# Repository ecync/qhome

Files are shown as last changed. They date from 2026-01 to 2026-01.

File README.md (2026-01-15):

# QHome Automation System

## 🏠 Project Overview
**QHome** is a comprehensive, full-stack IoT Smart Home solution designed to provide real-time monitoring, automation, and remote control of environmental and power sensors. The system is built on a modular architecture, spanning from custom PCB hardware design to a modern web-based dashboard.

This project integrates embedded systems connectivity (ESP32/ESP8266), robust backend services (NestJS/MQTT), and an interactive frontend (React) to create a seamless smart home experience.

## 🏗️ System Architecture

The system operates on a publish-subscribe model using MQTT for low-latency communication between the hardware nodes and the server.

```mermaid
graph LR
    subgraph Hardware Layer
        Node[ESP32 QHome Node]
        Sensors[Sensors: DHT, MQ, ACS, ZMPT]
        Relays[Relays & Actuators]
        Node --- Sensors
        Node --- Relays
    end

    subgraph Communication
        MQTT[MQTT Broker]
        WiFi[WiFi Network]
        Node -.->|MQTT/WS| WiFi
        WiFi -.-> MQTT
    end

    subgraph Cloud/Server Layer
        Backend[NestJS Backend]
        DB[(MongoDB)]
        Backend <-->|Pub/Sub| MQTT
        Backend <-->|Data Persistence| DB
    end

    subgraph User Interface
        Frontend[React Dashboard]
        User((User))
        User --> Frontend
        Frontend <-->|HTTP/REST| Backend
        Frontend <-->|Socket.io| Backend
    end
```

## 📊 Data Flow Diagram

This diagram illustrates how data moves through the entire system, from sensor acquisition to user visualization.

```mermaid
flowchart TB
    subgraph IoT_Node["IoT Node Layer"]
        Sensors[Physical Sensors<br/>DHT, MQ, ACS, ZMPT, PIR, LDR]
        ADC[Analog-to-Digital<br/>Conversion]
        Process[Data Processing<br/>& Aggregation]
        JSON[JSON Payload<br/>Generation]
        
        Sensors -->|Analog/Digital| ADC
        ADC -->|Raw Values| Process
        Process -->|Structured Data| JSON
    end
    
    subgraph Communication_Layer["Communication Layer"]
        WiFi[WiFi Module]
        MQTT_Pub[MQTT Publisher<br/>Topic: node/send]
        MQTT_Broker[MQTT Broker<br/>158.101.98.79:9001]
        MQTT_Sub[MQTT Subscriber<br/>Topic: node/cmd]
        
        JSON -->|Transmit| WiFi
        WiFi -->|Publish| MQTT_Pub
        MQTT_Pub -->|WebSocket| MQTT_Broker
        MQTT_Broker -->|Commands| MQTT_Sub
        MQTT_Sub -->|Receive| WiFi
    end
    
    subgraph Backend_Layer["Backend Service Layer"]
        Gateway[MQTT Gateway<br/>Service]
        Validator[Data Validator<br/>& Parser]
        EventEmitter[Event Emitter]
        DB_Write[Database Writer]
        Socket_Emit[Socket.IO Emitter]
        MongoDB[(MongoDB<br/>Collections)]
        API[REST API<br/>Controllers]
        
        MQTT_Broker -->|Subscribed Data| Gateway
        Gateway -->|Validate| Validator
        Validator -->|Emit Events| EventEmitter
        EventEmitter -->|Store| DB_Write
        EventEmitter -->|Broadcast| Socket_Emit
        DB_Write -->|Persist| MongoDB
        API -->|Query| MongoDB
    end
    
    subgraph Frontend_Layer["Frontend Application Layer"]
        Socket_Client[Socket.IO Client]
        State[React State<br/>Management]
        UI_Dashboard[Dashboard UI<br/>Components]
        UI_Analytics[Analytics UI<br/>Charts]
        HTTP_Client[HTTP Client<br/>API Service]
        
        Socket_Emit -.->|Real-time Push| Socket_Client
        Socket_Client -->|Update| State
        HTTP_Client -->|Fetch Historical| API
        API -->|Response| HTTP_Client
        HTTP_Client -->|Update| State
        State -->|Render| UI_Dashboard
        State -->|Render| UI_Analytics
    end
    
    subgraph User_Layer["User Interaction"]
        User((User))
        Browser[Web Browser]
        
        User -->|View/Control| Browser
        Browser <-->|Display| UI_Dashboard
        Browser <-->|Display| UI_Analytics
        Browser -->|Commands| HTTP_Client
    end
    
    HTTP_Client -.->|Control Commands| API
    API -.->|Publish to node/cmd| MQTT_Broker
    
    style IoT_Node fill:#e1f5ff
    style Communication_Layer fill:#fff3e0
    style Backend_Layer fill:#f3e5f5
    style Frontend_Layer fill:#e8f5e9
    style User_Layer fill:#fce4ec
```

### Data Flow Description

**1. Sensor Data Acquisition (IoT Node)**
- Physical sensors continuously monitor environmental and power parameters
- Analog sensors output voltage levels converted to digital values via ADC
- Data is processed, calibrated, and packaged into JSON format

**2. Data Transmission (Communication Layer)**
- JSON payload transmitted over WiFi to MQTT broker
- Published to `node/send` topic via WebSocket protocol
- Bidirectional communication allows receiving commands on `node/cmd` topic

**3. Data Processing (Backend Service)**
- MQTT Gateway subscribes to node data streams
- Incoming data is validated and parsed
- Event system triggers parallel operations:
  - Persistent storage in MongoDB collections
  - Real-time broadcast to connected frontend clients via Socket.IO

**4. Data Presentation (Frontend Application)**
- Socket.IO client receives real-time updates for live dashboard
- HTTP client fetches historical data for analytics and trends
- React state management updates UI components reactively

**5. User Control Loop**
- User interactions trigger API calls to backend
- Backend publishes control commands to MQTT broker
- IoT node receives and executes commands (relay control, configuration updates)

## 🔄 Software Flow Diagram

This diagram shows the complete software execution flow from system startup to continuous operation.

```mermaid
flowchart TD
    Start([System Power On]) --> Init_Check{Component<br/>Ready?}
    
    Init_Check -->|Hardware| Init_Hardware[Initialize Hardware<br/>• GPIO Pins<br/>• LCD Display<br/>• Sensors<br/>• Relays]
    Init_Check -->|Backend| Init_Backend[Initialize Backend<br/>• Load Config<br/>• Connect MongoDB<br/>• Start HTTP Server]
    Init_Check -->|Frontend| Init_Frontend[Initialize Frontend<br/>• Load React App<br/>• Check Session<br/>• Setup Routes]
    
    Init_Hardware --> Check_Config{Config<br/>Exists?}
    Check_Config -->|No| AP_Mode[Start WiFi AP Mode<br/>Show Config Portal]
    AP_Mode --> Wait_Config[Wait for User<br/>to Configure WiFi]
    Wait_Config -->|Configured| Save_Config[Save to EEPROM]
    Save_Config --> Connect_WiFi
    
    Check_Config -->|Yes| Connect_WiFi[Connect to WiFi]
    Connect_WiFi --> WiFi_Success{Connected?}
    WiFi_Success -->|No| AP_Mode
    WiFi_Success -->|Yes| Connect_MQTT[Connect to<br/>MQTT Broker]
    
    Connect_MQTT --> MQTT_Success{Connected?}
    MQTT_Success -->|No| Retry_MQTT[Retry Connection<br/>Exponential Backoff]
    Retry_MQTT --> MQTT_Success
    MQTT_Success -->|Yes| Subscribe_Topics[Subscribe to<br/>node/cmd Topic]
    
    Init_Backend --> Connect_DB[Connect to MongoDB]
    Connect_DB --> DB_Success{Connected?}
    DB_Success -->|No| Error_Exit[Log Error & Exit]
    DB_Success -->|Yes| Connect_MQTT_Backend[Connect to<br/>MQTT Broker as Client]
    Connect_MQTT_Backend --> Backend_Subscribe[Subscribe to<br/>node/send Topic]
    Backend_Subscribe --> Start_API[Start REST API<br/>& Socket.IO Server]
    
    Init_Frontend --> Check_Auth{User<br/>Authenticated?}
    Check_Auth -->|No| Show_Login[Show Login Page]
    Show_Login --> User_Login[User Enters<br/>Credentials]
    User_Login --> Validate_Auth[Validate Against<br/>Backend API]
    Validate_Auth --> Auth_Valid{Valid?}
    Auth_Valid -->|No| Show_Login
    Auth_Valid -->|Yes| Store_Session[Store Session<br/>in SessionStorage]
    
    Check_Auth -->|Yes| Load_Dashboard
    Store_Session --> Load_Dashboard[Load Dashboard<br/>Components]
    Load_Dashboard --> Connect_Socket[Connect Socket.IO<br/>to Backend]
    
    Subscribe_Topics --> Ready_Node[Node Ready<br/>Play Beep Sound]
    Start_API --> Ready_Backend[Backend Ready<br/>Log Status]
    Connect_Socket --> Ready_Frontend[Frontend Ready<br/>Display Dashboard]
    
    Ready_Node --> Main_Loop_Node[Main Loop: Node]
    Ready_Backend --> Main_Loop_Backend[Main Loop: Backend]
    Ready_Frontend --> Main_Loop_Frontend[Main Loop: Frontend]
    
    Main_Loop_Node --> Read_Sensors[Read All Sensors<br/>Every Interval]
    Read_Sensors --> Process_Data[Process & Calculate<br/>• Temperature/Humidity<br/>• Gas Level<br/>• Power/Energy<br/>• Motion/Light]
    Process_Data --> Check_Thresholds{Thresholds<br/>Exceeded?}
    Check_Thresholds -->|Yes| Trigger_Alert[Trigger Local Alert<br/>• Activate Buzzer<br/>• Update LCD<br/>• Send MQTT Alert]
    Check_Thresholds -->|No| Check_Sync
    Trigger_Alert --> Check_Sync
    
    Check_Sync{Time to<br/>Sync?} -->|Yes| Publish_Data[Publish JSON<br/>to node/send]
    Check_Sync -->|No| Update_Display
    Publish_Data --> Update_Display[Update LCD<br/>Display Status]
    
    Update_Display --> Listen_Commands[Listen for<br/>MQTT Commands]
    Listen_Commands --> Command_Received{Command?}
    Command_Received -->|Yes| Execute_Command[Execute Command<br/>• Toggle Relay<br/>• Update Config<br/>• Restart]
    Command_Received -->|No| Main_Loop_Node
    Execute_Command --> Main_Loop_Node
    
    Main_Loop_Backend --> Listen_MQTT[Listen for<br/>MQTT Messages]
    Listen_MQTT --> MQTT_Message{Message<br/>Received?}
    MQTT_Message -->|Yes| Parse_Message[Parse Message Type<br/>• _sensor_data<br/>• _alert<br/>• _error<br/>• _ack]
    MQTT_Message -->|No| Handle_HTTP
    
    Parse_Message --> Save_DB[Save to MongoDB<br/>Appropriate Collection]
    Save_DB --> Emit_Socket[Emit to Socket.IO<br/>Connected Clients]
    Emit_Socket --> Handle_HTTP
    
    Handle_HTTP[Handle HTTP Requests<br/>• GET sensor-data<br/>• POST commands<br/>• POST config]
    Handle_HTTP --> API_Request{Request?}
    API_Request -->|GET| Query_DB[Query MongoDB<br/>Return Results]
    API_Request -->|POST| Publish_Command[Publish to<br/>node/cmd Topic]
    API_Request -->|None| Main_Loop_Backend
    Query_DB --> Main_Loop_Backend
    Publish_Command --> Main_Loop_Backend
    
    Main_Loop_Frontend --> Socket_Listen[Listen for<br/>Socket.IO Events]
    Socket_Listen --> Socket_Event{Event<br/>Received?}
    Socket_Event -->|Yes| Update_State[Update React State<br/>Trigger Re-render]
    Socket_Event -->|No| User_Action
    Update_State --> User_Action
    
    User_Action{User<br/>Action?}
    User_Action -->|View Analytics| Fetch_History[Fetch Historical<br/>Data via API]
    User_Action -->|Send Command| Send_Command[Send POST Request<br/>to Backend API]
    User_Action -->|Update Settings| Send_Config[Send Config Update<br/>to Backend API]
    User_Action -->|None| Main_Loop_Frontend
    
    Fetch_History --> Render_Charts[Render Charts<br/>with Recharts]
    Render_Charts --> Main_Loop_Frontend
    Send_Command --> Main_Loop_Frontend
    Send_Config --> Main_Loop_Frontend
    
    style Init_Hardware fill:#e1f5ff
    style Init_Backend fill:#f3e5f5
    style Init_Frontend fill:#e8f5e9
    style Main_Loop_Node fill:#ffebee
    style Main_Loop_Backend fill:#fff3e0
    style Main_Loop_Frontend fill:#e0f2f1
```

## 📂 Project Modules

The repository is organized into four main operational layers. Click on the module links for detailed documentation, installation steps, and API references.

| Module | Directory | Description | Technology |
| :--- | :--- | :--- | :--- |
| **Hardware Design** | [**`/pcb`**](pcb/README.md) | Custom PCB layouts, schematics, and BOM. | Eagle CAD / Fusion 360 |
| **Firmware** | [**`/node`**](node/README.md) | C++ firmware for ESP controllers implementing sensor logic. | Arduino / C++ |
| **Backend API** | [**`/backend`**](backend/README.md) | Server logic, database management, and MQTT processing. | NestJS, MongoDB, TypeScript |
| **Frontend UI** | [**`/frontend`**](frontend/README.md) | Web dashboard for monitoring and control. | React, Vite, Tailwind CSS |

## ✨ Key Features

*   **Real-time Monitoring**: Live streaming of Temperature, Humidity, Air Quality (Gas), and Ambient Light levels.
*   **Energy Management**: Precise AC Voltage, Current, Power (W), and Energy (kWh) metering using ZMPT101B and ACS712 sensors.
*   **Safety & Alerts**: Instant automated alerts for gas leaks, fire detection, or abnormal power usage via Buzzer and MQTT push notifications.
*   **Remote Control**: Toggle lights and appliances remotely via the web dashboard.
*   **Data Analytics**: Historical charts and graphs to track power consumption and environmental trends over time.
*   **Secure Access**: Token-based authentication (Custom Headers) ensuring only authorized users can control the system.

## 🚀 Getting Started

To spin up the entire system locally, follow the **Installation & Setup** guides in each module's README. A high-level startup order is recommended:

1.  **Infrastructure**: Ensure you have a MongoDB instance and an MQTT Broker (e.g., Mosquitto) running.
2.  **Backend**: Start the [Backend Service](backend/README.md) to initialize the API and Database connections.
3.  **Frontend**: Launch the [Web Dashboard](frontend/README.md) to interact with the system.
4.  **Hardware**: Flash the [Firmware](node/README.md) to your ESP32/ESP8266 device and configure it to connect to your Wi-Fi and MQTT Broker.

## 🛠️ Technology Stack

*   **Hardware**: ESP32, ESP8266, DHT11/22, MQ-135, ACS712, ZMPT101B, Relay Modules.
*   **Protocol**: MQTT (Message Queuing Telemetry Transport) over WebSockets.
*   **Server**: Node.js, NestJS, Mongoose.
*   **Database**: MongoDB (NoSQL).
*   **Client**: React.js, TypeScript, Tailwind CSS, Recharts.

---
*Developed by Eshan Chathuranga*

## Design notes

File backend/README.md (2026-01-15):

# Backend Service - QHome Automation System

## Overview
The **Backend Service** acts as the central intelligence of the Home Automation System. It is built with **NestJS** and serves two primary roles:
1.  **API Server**: Provides a RESTful API for the frontend dashboard to fetch data and update settings.
2.  **MQTT Broker/Client**: Connects to the IoT Nodes via MQTT (over WebSockets) to receive sensor telemetry and dispatch control commands.

## Technology Stack

| Category | Technology | Usage |
| :--- | :--- | :--- |
| **Framework** | [NestJS](https://nestjs.com/) | Server-side application framework |
| **Language** | [TypeScript](https://www.typescriptlang.org/) | Type-safe development |
| **Database** | [MongoDB](https://www.mongodb.com/) | NoSQL database for flexible sensor data storage |
| **ODM** | [Mongoose](https://mongoosejs.com/) | Object Data Modeling for MongoDB |
| **Messaging** | [MQTT](https://mqtt.org/) | IoT communication protocol |
| **Runtime** | [Node.js](https://nodejs.org/) | JavaScript runtime environment |

## Architecture

The backend follows a modular monolith architecture provided by NestJS.

```mermaid
graph TD
    Device[IoT Node] -->|MQTT Publish| Broker[MQTT Broker]
    Broker -->|Subscribe| NestJS[NestJS Backend]
    
    NestJS -->|Process| MqttService[MQTT Service]
    
    MqttService -->|Save Data| MongoDB[(MongoDB Database)]
    MqttService -->|Events| EventEmitter[Event Emitter]
    
    User[Frontend User] -->|HTTP Req| API[REST API Controller]
    API -->|Auth Guard| Auth[Authentication]
    Auth -- Valid --> Service[App Service]
    Service -->|Query| MongoDB
    
    Service -->|Command| MqttService
    MqttService -->|Publish| Broker
    Broker -->|Receive| Device
```

## 🔄 Data Processing Flow

This diagram details how the backend processes incoming MQTT messages and serves data to clients.

```mermaid
flowchart TD
    Start([MQTT Message Received]) --> Gateway[MQTT Gateway<br/>mqtt.gateway.ts]
    Gateway --> ParseMessage{Parse Message<br/>Structure}
    
    ParseMessage -->|Valid JSON| ExtractType[Extract Message Type<br/>from payload.type]
    ParseMessage -->|Invalid| LogError[Log Parse Error]
    LogError --> SendErrorResponse[Emit Error Event]
    SendErrorResponse --> End1([End])
    
    ExtractType --> TypeSwitch{Message Type?}
    
    TypeSwitch -->|_sensor_data| ProcessSensor[Process Sensor Data]
    TypeSwitch -->|_alert| ProcessAlert[Process Alert]
    TypeSwitch -->|_error| ProcessError[Process Error]
    TypeSwitch -->|_ack| ProcessAck[Process Acknowledgment]
    TypeSwitch -->|Unknown| LogUnknown[Log Unknown Type]
    LogUnknown --> End2([End])
    
    ProcessSensor --> ValidateSensor[Validate Sensor Schema<br/>• Check required fields<br/>• Validate data types<br/>• Range validation]
    ValidateSensor --> SensorValid{Valid?}
    SensorValid -->|No| LogValidationError[Log Validation Error]
    LogValidationError --> End3([End])
    
    SensorValid -->|Yes| TransformData[Transform Data<br/>• Convert units<br/>• Calculate derived values<br/>• Add timestamp]
    TransformData --> CreateSensorDoc[Create NodeSensorData<br/>Document]
    
    CreateSensorDoc --> SaveSensor[Save to MongoDB<br/>nodeSensorData collection]
    SaveSensor --> SensorSaved{Saved?}
    SensorSaved -->|Error| LogDBError1[Log Database Error]
    LogDBError1 --> End4([End])
    
    SensorSaved -->|Success| EmitSensorEvent[Emit 'sensorUpdate' Event]
    EmitSensorEvent --> BroadcastSocket1[Broadcast via Socket.IO<br/>to all connected clients]
    BroadcastSocket1 --> CheckThresholds[Check Alert Thresholds<br/>• Temperature limits<br/>• Gas levels<br/>• Power anomalies]
    CheckThresholds --> ThresholdExceeded{Threshold<br/>Exceeded?}
    ThresholdExceeded -->|Yes| CreateAutoAlert[Create Automatic Alert]
    CreateAutoAlert --> ProcessAlert
    ThresholdExceeded -->|No| End5([End])
    
    ProcessAlert --> ValidateAlert[Validate Alert Schema<br/>• alert_type required<br/>• Validate severity]
    ValidateAlert --> AlertValid{Valid?}
    AlertValid -->|No| LogAlertError[Log Validation Error]
    LogAlertError --> End6([End])
    
    AlertValid -->|Yes| EnrichAlert[Enrich Alert Data<br/>• Add timestamp<br/>• Add severity level<br/>• Add node identifier]
    EnrichAlert --> CreateAlertDoc[Create NodeAlert<br/>Document]
    CreateAlertDoc --> SaveAlert[Save to MongoDB<br/>nodeAlert collection]
    SaveAlert --> AlertSaved{Saved?}
    AlertSaved -->|Error| LogDBError2[Log Database Error]
    LogDBError2 --> End7([End])
    
    AlertSaved -->|Success| EmitAlertEvent[Emit 'criticalAlert' Event]
    EmitAlertEvent --> BroadcastSocket2[Broadcast via Socket.IO<br/>HIGH PRIORITY]
    BroadcastSocket2 --> TriggerNotification[Trigger Push Notification<br/>If configured]
    TriggerNotification --> End8([End])
    
    ProcessError --> ValidateError[Validate Error Schema<br/>• error_type required<br/>• Validate message]
    ValidateError --> ErrorValid{Valid?}
    ErrorValid -->|No| LogErrorValidation[Log Validation Error]
    LogErrorValidation --> End9([End])
    
    ErrorValid -->|Yes| CreateErrorDoc[Create NodeError<br/>Document]
    CreateErrorDoc --> SaveError[Save to MongoDB<br/>nodeError collection]
    SaveError --> ErrorSaved{Saved?}
    ErrorSaved -->|Error| LogDBError3[Log Database Error]
    LogDBError3 --> End10([End])
    
    ErrorSaved -->|Success| EmitErrorEvent[Emit 'systemError' Event]
    EmitErrorEvent --> BroadcastSocket3[Broadcast via Socket.IO]
    BroadcastSocket3 --> CheckCritical{Critical<br/>Error?}
    CheckCritical -->|Yes| SendAdminAlert[Send Admin Notification]
    SendAdminAlert --> End11([End])
    CheckCritical -->|No| End12([End])
    
    ProcessAck --> LogAck[Log Acknowledgment]
    LogAck --> UpdateCommandStatus[Update Command Status<br/>In tracking system]
    UpdateCommandStatus --> EmitAckEvent[Emit 'commandAck' Event]
    EmitAckEvent --> BroadcastSocket4[Broadcast via Socket.IO]
    BroadcastSocket4 --> End13([End])
    
    style ProcessSensor fill:#e3f2fd
    style ProcessAlert fill:#ffebee
    style ProcessError fill:#fff3e0
    style ProcessAck fill:#e8f5e9
    style SaveSensor fill:#f3e5f5
    style SaveAlert fill:#f3e5f5
    style SaveError fill:#f3e5f5
```

### Data Processing Pipeline Stages

**1. Message Reception & Parsing**
- MQTT Gateway receives raw message from broker
- JSON parsing with error handling
- Message type extraction from payload structure

**2. Validation Layer**
- Schema validation using TypeScript interfaces
- Required field verification
- Data type and range checks
- Malformed data rejection with logging

**3. Data Transformation**
- Unit conversions (e.g., ADC values to physical units)
- Calculated fields (e.g., power = voltage × current)
- Timestamp normalization
- Data enrichment with metadata

**4. Persistence Layer**
- Mongoose ODM for MongoDB operations
- Atomic write operations
- Error handling and retry logic
- Index optimization for queries

**5. Event Broadcasting**
- Event-driven architecture using NestJS EventEmitter
- Socket.IO real-time push to connected clients
- Priority-based message queuing for alerts
- Client-specific filtering and routing

**6. Threshold Monitoring**
- Continuous evaluation of sensor values against configured thresholds
- Automatic alert generation for anomalies
- Cascading alert processing
- Rate limiting to prevent alert storms

---

## 🌐 REST API Request Flow

```mermaid
flowchart TD
    HTTPRequest([HTTP Request]) --> Controller[API Controller<br/>@Controller /mqtt]
    Controller --> CheckAuth{Authentication<br/>Guard}
    
    CheckAuth -->|Missing Headers| Return401[Return 401<br/>Unauthorized]
    Return401 --> EndReq1([End Request])
    
    CheckAuth -->|Invalid Credentials| Return403[Return 403<br/>Forbidden]
    Return403 --> EndReq2([End Request])
    
    CheckAuth -->|Valid| RouteMethod{Route<br/>Method?}
    
    RouteMethod -->|GET /status| GetStatus[Query NodeConfig<br/>from MongoDB]
    GetStatus --> ReturnConfig[Return 200<br/>with config JSON]
    ReturnConfig --> EndReq3([End Request])
    
    RouteMethod -->|GET /errors| GetErrors[Query NodeError<br/>Collection]
    GetErrors --> ApplyLimit[Apply Limit Query Param]
    ApplyLimit --> SortDesc[Sort by createdAt DESC]
    SortDesc --> ReturnErrors[Return 200<br/>with error array]
    ReturnErrors --> EndReq4([End Request])
    
    RouteMethod -->|GET /alerts| GetAlerts[Query NodeAlert<br/>Collection]
    GetAlerts --> ApplyLimitAlerts[Apply Limit Query Param]
    ApplyLimitAlerts --> SortDescAlerts[Sort by createdAt DESC]
    SortDescAlerts --> ReturnAlerts[Return 200<br/>with alert array]
    ReturnAlerts --> EndReq5([End Request])
    
    RouteMethod -->|GET /sensor-data/:date| ParseDate[Parse Date Parameter]
    ParseDate --> DateValid{Valid<br/>Timestamp?}
    DateValid -->|No| Return400[Return 400<br/>Bad Request]
    Return400 --> EndReq6([End Request])
    DateValid -->|Yes| QueryByDate[Query NodeSensorData<br/>by date range]
    QueryByDate --> Aggregate[Aggregate & Group Data]
    Aggregate --> ReturnData[Return 200<br/>with sensor data array]
    ReturnData --> EndReq7([End Request])
    
    RouteMethod -->|POST /command/:cmd| ValidateCommand[Validate Command Type]
    ValidateCommand --> CommandValid{Valid<br/>Command?}
    CommandValid -->|No| Return400Cmd[Return 400<br/>Invalid Command]
    Return400Cmd --> EndReq8([End Request])
    
    CommandValid -->|Yes| CreateCmdPayload["Create Command Payload<br/>{type: '_command', payload: {cmd: ...}}"]
    CreateCmdPayload --> PublishMQTT1[Publish to MQTT<br/>Topic: node/cmd]
    PublishMQTT1 --> MQTTPublished1{Published?}
    MQTTPublished1 -->|Error| Return500Pub1[Return 500<br/>Publish Failed]
    Return500Pub1 --> EndReq9([End Request])
    MQTTPublished1 -->|Success| Return202Cmd[Return 202<br/>Accepted]
    Return202Cmd --> EndReq10([End Request])
    
    RouteMethod -->|POST /config| ValidateConfigSchema[Validate Config Schema<br/>against interface]
    ValidateConfigSchema --> ConfigValid{Valid<br/>Schema?}
    ConfigValid -->|No| Return400Config[Return 400<br/>Invalid Config]
    Return400Config --> EndReq11([End Request])
    
    ConfigValid -->|Yes| UpdateDBConfig[Update NodeConfig<br/>in MongoDB]
    UpdateDBConfig --> DBUpdated{Updated?}
    DBUpdated -->|Error| Return500DB[Return 500<br/>Database Error]
    Return500DB --> EndReq12([End Request])
    
    DBUpdated -->|Success| CreateConfigPayload["Create Config Payload<br/>{type: '_config_update', payload: {config: ...}}"]
    CreateConfigPayload --> PublishMQTT2[Publish to MQTT<br/>Topic: node/cmd]
    PublishMQTT2 --> MQTTPublished2{Published?}
    MQTTPublished2 -->|Error| Return500Pub2[Return 500<br/>Publish Failed]
    Return500Pub2 --> EndReq13([End Request])
    MQTTPublished2 -->|Success| Return202Config[Return 202<br/>Accepted]
    Return202Config --> EndReq14([End Request])
    
    style CheckAuth fill:#ffebee
    style GetStatus fill:#e3f2fd
    style GetErrors fill:#e3f2fd
    style GetAlerts fill:#e3f2fd
    style QueryByDate fill:#e3f2fd
    style PublishMQTT1 fill:#fff3e0
    style PublishMQTT2 fill:#fff3e0
    style UpdateDBConfig fill:#f3e5f5
```

---

## Directory Structure
```
backend/
├── src/
│   ├── mqtt/               # MQTT Module
│   │   ├── mqtt.gateway.ts # Handles socket events
│   │   ├── mqtt.service.ts # Business logic for messaging
│   │   └── auth.guard.ts   # API Authentication
│   ├── schema/             # Mongoose Data Models
│   │   ├── node.sensor.data.schema.ts
│   │   ├── node.config.schema.ts
│   │   └── ...
│   ├── app.module.ts       # Root Module
│   └── main.ts             # Entry point
└── package.json
```

## Documentation
- [API Reference](API.md) - Detailed description of HTTP Endpoints and MQTT topics.

## Data Models

The system uses MongoDB schemas to organize data:

*   **NodeSensorData**: Stores historical readings (Temp, Humidity, Gas, Light, Power).
*   **NodeConfig**: Remote configuration for nodes (Thresholds, Intervals).
*   **NodeAlert**: Critical events (Gas leak, Fire detection).
*   **NodeError**: System health logs (Sensor failures).

## API & Authentication

### Security
The API is protected using custom headers. All HTTP requests must include:
*   `X-USERNAME`: Configured username
*   `X-PASSWORD`: Configured password

### Integration
The backend connects to an MQTT broker over **WebSockets** (host: `158.101.98.79`, port: `9001`). This allows it to function in environments where raw TCP MQTT ports might be restricted, and enables easy integration with web-based clients.

## Installation & Setup

### Prerequisites
*   Node.js (v18+)
*   MongoDB Instance (Local or Atlas)
*   MQTT Broker (Mosquitto or similar, supporting WebSockets)

### Environment Variables
Create a `.env` file in the root directory:
```env
MONGO_URI=mongodb://localhost:27017/qhome
API_USERNAME=admin
API_PASSWORD=secret
PORT=3000
```

### Steps

1.  **Install Application**
    ```bash
    cd backend
    npm install
    ```

2.  **Start Development Server**
    ```bash
    npm run start:dev
    ```
    The server will start on `http://localhost:3000` (API) and connect to the MQTT Broker.

3.  **Build for Production**
    ```bash
    npm run build
    npm run start:prod
    ```

## Visuals
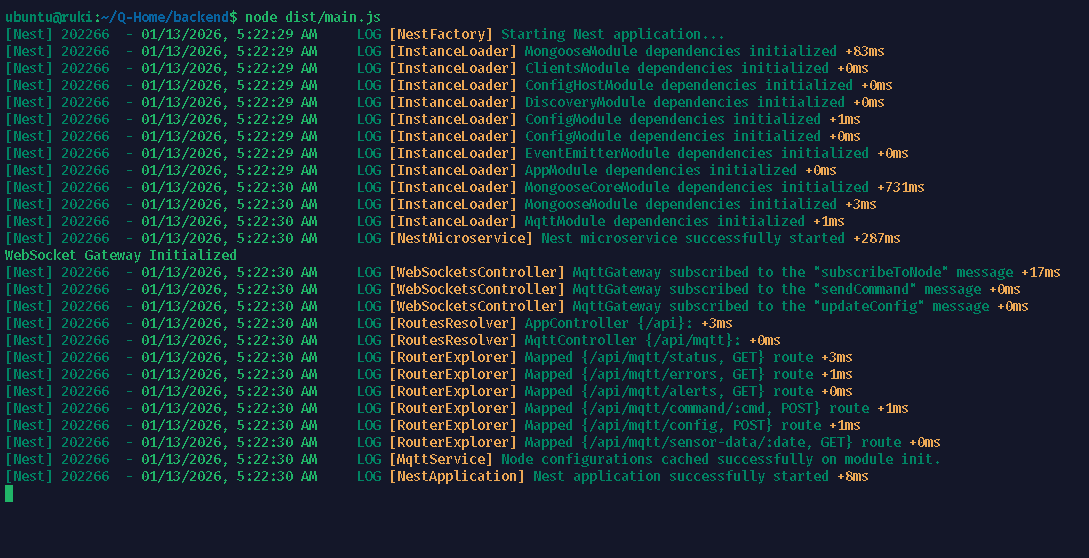
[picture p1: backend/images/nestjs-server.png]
NestJS Server Concept


---

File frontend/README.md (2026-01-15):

# Frontend Web Application - QHome Automation System

## Overview
The **Frontend Web Application** serves as the user interface for the Smart Home Automation System. Built with **React** and **Vite**, it provides a responsive, modern dashboard for real-time monitoring, control, and data analysis of connected IoT nodes.

## Features
- **📊 Real-time Dashboard**: Live monitoring of sensor data (Temperature, Humidity, Gas, Power, etc.) via Websockets/MQTT integration.
- **🔐 Secure Authentication**: User verification system protecting access to controls and configuration.
- **📈 Analytics**: Interactive charts visualizing historical sensor data using `recharts`.
- **⚙️ Remote Configuration**: Interface to update system settings and node parameters remotely.
- **📱 Responsive Design**: Built with **Tailwind CSS** for a seamless experience across desktop and mobile devices.

## Technology Stack

| Category | Technology | Usage |
| :--- | :--- | :--- |
| **Framework** | [React 18+](https://react.dev/) | Component-based UI architecture |
| **Build Tool** | [Vite](https://vitejs.dev/) | Ultra-fast development server and bundling |
| **Styling** | [Tailwind CSS](https://tailwindcss.com/) | Utility-first CSS framework |
| **Routing** | [React Router 6](https://reactrouter.com/) | Client-side navigation |
| **Charts** | [Recharts](https://recharts.org/) | Data visualization |
| **Icons** | [Lucide React](https://lucide.dev/) | Consistent & clean icon set |
| **Connectivity** | [Socket.io-client](https://socket.io/) | Real-time bidirectional communication |

## Application Structure

### Directory Layout
```
frontend/
├── src/
│   ├── components/     # UI Pages & Widgets
│   │   ├── Analytics.tsx
│   │   ├── Dashboard.tsx
│   │   ├── Layout.tsx
│   │   ├── Login.tsx
│   │   └── Settings.tsx
│   ├── hooks/          # Custom React Hooks
│   ├── utils/          # API & Helper functions
│   ├── App.tsx         # Main Routing Logic
│   └── main.tsx        # Entry Point
├── images/             # Documentation screenshots
└── package.json        # Dependencies & Scripts
```

## User Interface

### 1. Dashboard
The central hub displaying live cards for all active nodes.
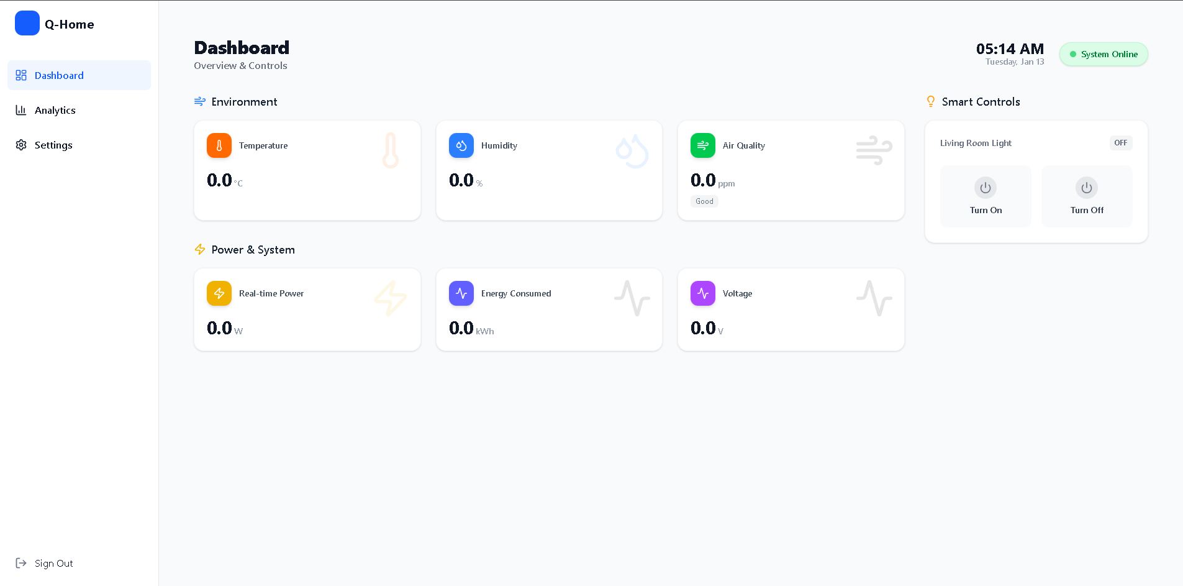
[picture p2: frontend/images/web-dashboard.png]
Dashboard


### 2. Analytics
Historical data visualization for power consumption and environmental trends.
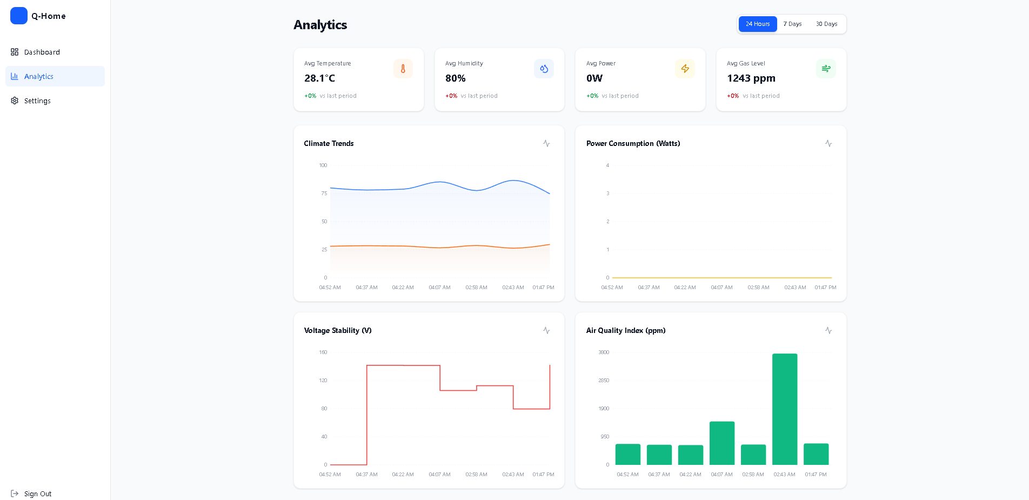
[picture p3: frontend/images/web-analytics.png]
Analytics


### 3. Settings
Configuration panel for user management and system preferences.
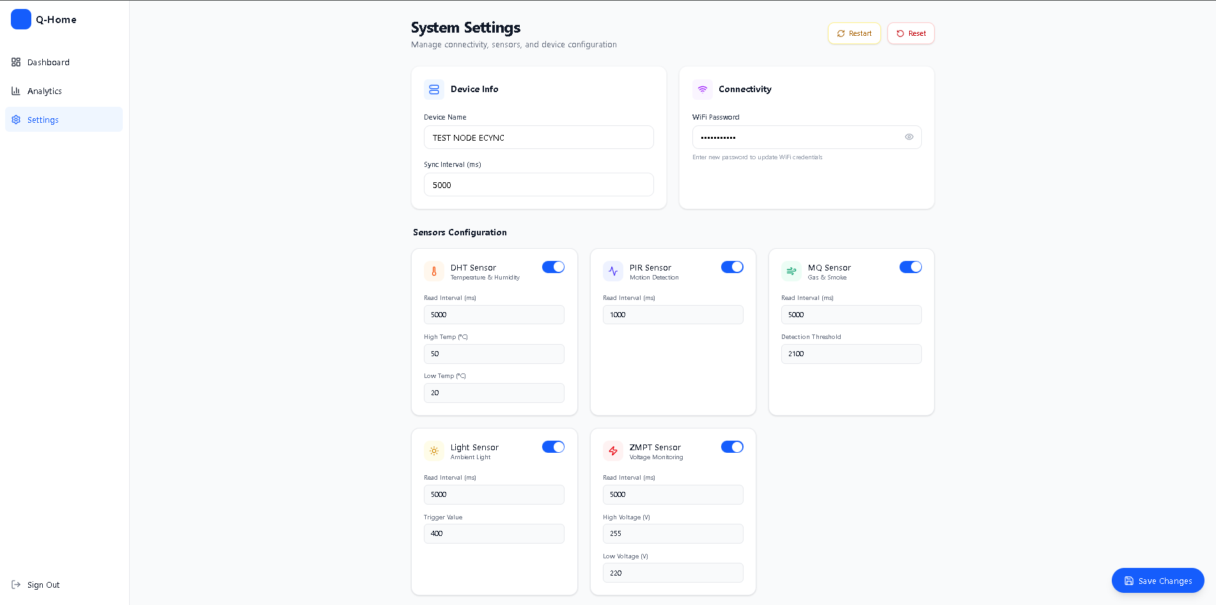
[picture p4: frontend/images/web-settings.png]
Settings


### 4. Login
Secure entry point.
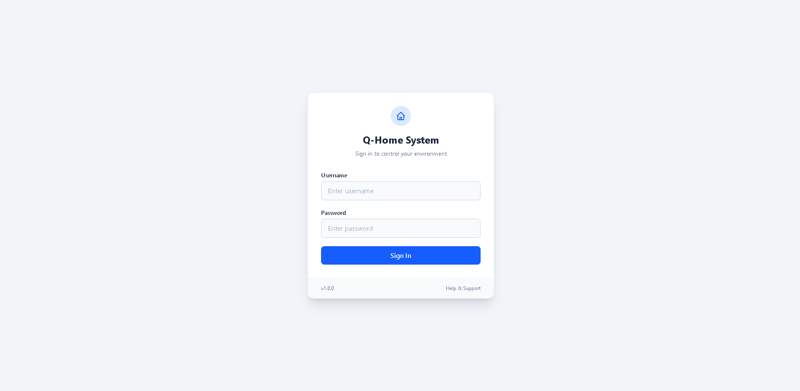
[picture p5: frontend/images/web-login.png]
Login


## System Architecture

### Application Flow
```mermaid
graph TD
    User((User)) -->|Visits| Browse[Browser]
    Browse -->|Checks Session| Auth{Authenticated?}
    
    Auth -- No --> Login[Login Page]
    Login -->|Credentials| API[Backend API]
    API -- Success --> Session[Set Session Storage]
    Session --> Dashboard
    
    Auth -- Yes --> Layout[Main Layout]
    
    Layout -->|route: /| Dashboard[Dashboard View]
    Layout -->|route: /analytics| Analytics[Analytics View]
    Layout -->|route: /settings| Settings[Settings View]
    
    Dashboard -->|Subscribes| Socket[Socket.IO / MQTT]
    Socket -->|Updates| LiveData[Real-time UI Updates]
```

## 👤 User Interaction Flow Diagram

This diagram shows detailed user journeys through the application and how actions trigger backend operations.

```mermaid
flowchart TD
    Start([User Opens Browser]) --> LoadApp[Load React Application]
    LoadApp --> CheckSession{Session<br/>Storage?}
    
    CheckSession -->|No Session| ShowLogin[Render Login Component]
    ShowLogin --> UserInput[User Enters<br/>Username & Password]
    UserInput --> ValidateInput{Input<br/>Validation}
    ValidateInput -->|Empty Fields| ShowInputError[Show Validation Error]
    ShowInputError --> UserInput
    
    ValidateInput -->|Valid| SendAuthRequest[POST Request to Backend<br/>Headers: X-USERNAME, X-PASSWORD]
    SendAuthRequest --> WaitResponse[Wait for Response]
    WaitResponse --> AuthResponse{Response?}
    
    AuthResponse -->|401/403| ShowAuthError[Show Authentication Error<br/>'Invalid Credentials']
    ShowAuthError --> UserInput
    
    AuthResponse -->|200 OK| SaveSession[Store Credentials<br/>in SessionStorage]
    SaveSession --> InitSocket[Initialize Socket.IO Connection]
    
    CheckSession -->|Valid Session| InitSocket
    InitSocket --> ConnectSocket[Connect to Backend<br/>ws://backend:3000]
    ConnectSocket --> SocketConnected{Connected?}
    SocketConnected -->|Error| ShowConnError[Show Connection Error<br/>Retry Logic]
    ShowConnError --> ConnectSocket
    
    SocketConnected -->|Success| SubscribeEvents[Subscribe to Socket Events<br/>• sensorUpdate<br/>• criticalAlert<br/>• commandAck<br/>• systemError]
    SubscribeEvents --> LoadLayout[Render Main Layout<br/>• Sidebar Navigation<br/>• Header with User Info<br/>• Content Outlet]
    
    LoadLayout --> NavigateDashboard[Default Route: Dashboard]
    
    NavigateDashboard --> RenderDashboard[Render Dashboard Component]
    RenderDashboard --> FetchInitialData[Fetch Initial Data<br/>GET /mqtt/status]
    FetchInitialData --> DisplayCards[Display Sensor Cards<br/>• Temperature/Humidity<br/>• Gas Level<br/>• Power Metrics<br/>• Light Status<br/>• Motion Status]
    
    DisplayCards --> MainLoop[Main Application Loop]
    
    MainLoop --> WaitEvent{User Action<br/>or Event?}
    
    WaitEvent -->|Socket: sensorUpdate| UpdateDashboard[Update Dashboard State<br/>Trigger Re-render]
    UpdateDashboard --> AnimateChange[Animate Value Changes]
    AnimateChange --> MainLoop
    
    WaitEvent -->|Socket: criticalAlert| ShowAlertModal[Show Alert Modal<br/>with Alert Details]
    ShowAlertModal --> PlayAlertSound[Play Alert Sound<br/>if enabled]
    PlayAlertSound --> MainLoop
    
    WaitEvent -->|Click: Quick Action Button| QuickAction{Action Type?}
    QuickAction -->|Toggle Light| SendToggleCmd[POST /mqtt/command/toggle_light]
    SendToggleCmd --> ShowLoading1[Show Loading Spinner]
    ShowLoading1 --> CmdResponse1{Response?}
    CmdResponse1 -->|202 Accepted| ShowSuccess1[Show Success Toast]
    ShowSuccess1 --> WaitAck1[Wait for Socket 'commandAck']
    WaitAck1 --> UpdateUI1[Update UI State]
    UpdateUI1 --> MainLoop
    CmdResponse1 -->|Error| ShowError1[Show Error Toast]
    ShowError1 --> MainLoop
    
    QuickAction -->|Restart System| ConfirmRestart[Show Confirmation Dialog]
    ConfirmRestart --> UserConfirm1{Confirmed?}
    UserConfirm1 -->|No| MainLoop
    UserConfirm1 -->|Yes| SendRestartCmd[POST /mqtt/command/restart]
    SendRestartCmd --> ShowLoading2[Show Loading Spinner]
    ShowLoading2 --> MainLoop
    
    WaitEvent -->|Click: Analytics Nav| NavigateAnalytics[Navigate to /analytics]
    NavigateAnalytics --> RenderAnalytics[Render Analytics Component]
    RenderAnalytics --> SelectDateRange[User Selects Date Range<br/>via Date Picker]
    SelectDateRange --> FetchHistorical[GET /mqtt/sensor-data/:date<br/>for each day in range]
    FetchHistorical --> ProcessData[Process & Aggregate Data<br/>• Calculate averages<br/>• Find min/max<br/>• Group by time intervals]
    ProcessData --> RenderCharts[Render Recharts Components<br/>• Line Chart: Temperature<br/>• Area Chart: Power Consumption<br/>• Bar Chart: Gas Levels]
    RenderCharts --> ChartsDisplayed[Display Interactive Charts<br/>with tooltips & zoom]
    ChartsDisplayed --> MainLoop
    
    WaitEvent -->|Click: Settings Nav| NavigateSettings[Navigate to /settings]
    NavigateSettings --> RenderSettings[Render Settings Component]
    RenderSettings --> DisplayForms[Display Configuration Forms<br/>• Node Settings<br/>• Sensor Thresholds<br/>• Sync Intervals]
    DisplayForms --> UserEditSettings[User Modifies Settings]
    UserEditSettings --> ValidateSettings{Valid<br/>Input?}
    ValidateSettings -->|No| ShowFormError[Show Form Validation Error]
    ShowFormError --> UserEditSettings
    
    ValidateSettings -->|Yes| ClickSave[User Clicks Save Button]
    ClickSave --> SendConfigUpdate[POST /mqtt/config<br/>Body: Updated Config JSON]
    SendConfigUpdate --> ShowLoading3[Show Loading Spinner]
    ShowLoading3 --> ConfigResponse{Response?}
    ConfigResponse -->|202 Accepted| ShowSuccess2[Show Success Toast<br/>'Configuration Updated']
    ShowSuccess2 --> WaitConfigAck[Wait for Socket 'configUpdated']
    WaitConfigAck --> RefreshSettings[Refresh Settings Display]
    RefreshSettings --> MainLoop
    ConfigResponse -->|Error| ShowError2[Show Error Toast<br/>Display Error Message]
    ShowError2 --> MainLoop
    
    WaitEvent -->|Click: Logout| ConfirmLogout[Show Confirmation Dialog]
    ConfirmLogout --> UserConfirm2{Confirmed?}
    UserConfirm2 -->|No| MainLoop
    UserConfirm2 -->|Yes| ClearSession[Clear SessionStorage]
    ClearSession --> DisconnectSocket[Disconnect Socket.IO]
    DisconnectSocket --> RedirectLogin[Redirect to Login Page]
    RedirectLogin --> ShowLogin
    
    WaitEvent -->|Socket: Disconnect| ShowReconnect[Show Reconnection Banner]
    ShowReconnect --> AttemptReconnect[Auto Reconnect Logic<br/>Exponential Backoff]
    AttemptReconnect --> ReconnectSuccess{Reconnected?}
    ReconnectSuccess -->|Yes| HideBanner[Hide Banner]
    HideBanner --> MainLoop
    ReconnectSuccess -->|No| ShowReconnectFailed[Show Connection Failed<br/>Manual Retry Option]
    ShowReconnectFailed --> UserRetry{User<br/>Retry?}
    UserRetry -->|Yes| ConnectSocket
    UserRetry -->|No| End([Application Idle])
    
    style ShowLogin fill:#ffebee
    style RenderDashboard fill:#e3f2fd
    style RenderAnalytics fill:#e8f5e9
    style RenderSettings fill:#fff3e0
    style ShowAlertModal fill:#ffcdd2
    style SendToggleCmd fill:#c8e6c9
    style SendConfigUpdate fill:#ffe0b2
```

### User Journey Highlights

**1. Authentication Flow**
- Session-based authentication using SessionStorage
- Credentials validated against backend API
- Persistent login across page refreshes
- Secure logout with session cleanup

**2. Real-time Dashboard Updates**
- WebSocket connection for live sensor data
- Automatic UI updates without page refresh
- Visual animations for value changes
- Critical alert notifications with sound

**3. Device Control**
- Quick action buttons for common commands
- Loading states and user feedback
- Acknowledgment tracking via Socket.IO
- Error handling with retry options

**4. Analytics & Historical Data**
- Interactive date range selection
- Multi-day data aggregation
- Responsive chart visualizations
- Export capabilities for data analysis

**5. Configuration Management**
- Form-based settings interface
- Client-side validation before submission
- Real-time sync confirmation
- Rollback capability on errors

**6. Error Handling & Recovery**
- Graceful connection loss handling
- Automatic reconnection with exponential backoff
- User-friendly error messages
- Manual retry mechanisms

---

### Component Hierarchy
```mermaid
graph TD
    App --> RouteProvider
    RouteProvider --> Login
    RouteProvider --> ProtectedLayout
    
    ProtectedLayout --> Sidebar
    ProtectedLayout --> Header
    ProtectedLayout --> Outlet
    
    Outlet --> Dashboard
    Dashboard --> SensorCard
    Dashboard --> QuickActions
    
    Outlet --> Analytics
    Analytics --> PowerChart
    Analytics --> EnvChart
    
    Outlet --> Settings
    Settings --> UserConfig
```

## Installation & Setup

### Prerequisites
- **Node.js**: v16 or higher
- **npm**: v7 or higher

### Steps
1.  **Navigate to frontend directory**:
    ```bash
    cd frontend
    ```
2.  **Install Dependencies**:
    ```bash
    npm install
    ```
3.  **Environment Setup**:
    Create a `.env` file (optional if defaults are used) to specify the backend URL.
    ```env
    VITE_API_URL=http://localhost:3000
    ```
4.  **Run Development Server**:
    ```bash
    npm run dev
    ```
    Access the app at `http://localhost:5173`.

5.  **Build for Production**:
    ```bash
    npm run build
    ```

## Integration Details
*   **Authentication**: Uses custom Headers `X-USERNAME` and `X-PASSWORD` stored in SessionStorage.
*   **Data Fetching**: The `src/utils/api.ts` module handles HTTP requests with automatic auth header injection.
*   **Real-time Updates**: Socket.io connects to the backend to receive live updates from the MQTT gateway, updating the Dashboard state without page reloads.

---

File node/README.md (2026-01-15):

# Node Firmware - QHome Automation System

## Overview
This directory contains the firmware source code for the **- QHome Automation Node**. The firmware is designed to run on ESP-based microcontrollers (e.g., ESP8266 or ESP32), managing a suite of environmental and power monitoring sensors while maintaining real-time communication with the central server via MQTT.

## Directory Structure
- **`main/`**: The core Arduino sketch files using a modular `.ino` structure.
    - `main.ino`: Application entry point and orchestrator.
    - `config.*`: Configuration management.
    - `mqtt.*`: MQTT protocol implementation.
    - `*_sensor.*`: Driver logic for individual sensors.
- **`libraries/`**: Local copies of required libraries ensuring compatibility and portability.
- **`images/`**: Documentation assets.

## Hardware Support
The firmware is built to drive a specific PCB layout (see `../pcb/`) populated with the following components:

### Sensors
- **DHT11/DHT22**: Temperature and Humidity monitoring.
- **MQ Series (e.g., MQ-2, MQ-135)**: Air quality and gas detection.
- **PIR Sensor**: Motion detection for security or presence automation.
- **LDR (Light Dependent Resistor)**: Ambient light level sensing.
- **ZMPT101B**: AC Voltage sensing.
- **ACS712**: Current sensing.

### Outputs
- **LCD I2C (16x2 or 20x4)**: Visual status feedback.
- **Buzzer/Alarm**: Audible feedback for alerts and startup confirmation.

## Pin Configuration
The firmware is pre-configured for the following [ESP32](https://www.espressif.com/en/products/socs/esp32) pin mapping.

| Component | Pin (GPIO) | Type | Description |
| :--- | :--- | :--- | :--- |
| **Connectivity** | | | |
| WiFi Indicator LED | 15 | Output | Blinks/On when connected |
| WiFi Reset Button | 18 | Input | Hold 5s to reset credentials |
| **System** | | | |
| System Button | 19 | Input | General purpose / Manual logic |
| Error LED | 32 | Output | Indicates sensor faults |
| Buzzer | 25 | Output | Audio alerts |
| **Sensors** | | | |
| DHT11/22 | 4 | Input/Output | Digital Temp/Hum |
| PIR Motion | 13 | Input | Digital Motion Detect |
| MQ Gas | 34 | Analog (ADC) | Air Quality |
| Light (LDR) | 35 | Analog (ADC) | Ambient Light |
| ZMPT101B | 36 | Analog (ADC) | AC Voltage |
| ACS712 | 39 | Analog (ADC) | AC Current |
| **Controls** | | | |
| Manual Light Btn | 23 | Input | Toggle Relays manually |
| Relay 1 | 26 | Output | Light Control 1 |
| Relay 2 | 27 | Output | Light Control 2 |
| MQ Indicator LED | 33 | Output | High Gas Alert |
- **ESP32 Board Support**: Install ESP32 board manager in Arduino IDE.

### Library Dependencies
The project relies on specific libraries included in the `libraries/` folder or available via Arduino Library Manager:
*   `ArduinoJson` (Serialization)
*   `PubSubClient` (MQTT)
*   `LiquidCrystal_I2C` (Display)
*   `DHT sensor library` (Temperature)
*   `Adafruit Unified Sensor` (Base for DHT)
*   `WiFiManager` (Connection Portal)
| **Display (I2C)** | | | |
| SDA | 21 | Data | LCD I2C Data |
| SCL | 22 | Clock | LCD I2C Clock |

## System Workflow

### Logic Flowchart
```mermaid
graph TD
    Start([Start]) --> Init[Initialize Components]
    Init --> LCD[Init LCD & Show Progress]
    LCD --> Config[Load Config]
    Config --> WiFi{WiFi Configured?}
    WiFi -- No --> APMode[Start AP Portal]
    WiFi -- Yes --> ConnectWiFi[Connect to WiFi]
    ConnectWiFi --> MQTT[Init MQTT]
    MQTT --> Sensors[Init Sensors: DHT, MQ, Light, PIR, ZMPT, ACS]
    Sensors --> Ready[System Ready beep]
    
    Ready --> Loop((Main Loop))
    
    Loop --> Portal{AP Mode?}
    Portal -- Yes --> HandlePortal[Handle WiFi Client] --> Loop
    Portal -- No --> CheckWiFi[Check WiFi Status]
    
    CheckWiFi --> MQTTMaintain[Maintain MQTT]
    MQTTMaintain --> ReadSensors[Handle Sensor Logic]
    
    ReadSensors --> DHT[DHT: Temp/Hum]
    ReadSensors --> MQ[MQ: Gas Levels]
    ReadSensors --> Light[Light: Lux & Relays]
    ReadSensors --> PIR[PIR: Motion]
    ReadSensors --> Power[Power: V/A/kWh]
    
    DHT --> AlertCheck{Threshold?}
    MQ --> AlertCheck
    Power --> AlertCheck
    
    AlertCheck -- Yes --> Action[Trigger Relay/Buzzer]
    AlertCheck -- No --> SyncTime{Sync Time?}
    
    Action --> SyncTime
    
    SyncTime -- Yes --> Publish[Publish MQTT Data]
    SyncTime -- No --> UpdateLCD[Update LCD Screens]
    
    Publish --> UpdateLCD
    UpdateLCD --> Loop
```

## 📡 Sensor Data Publishing Flow

This diagram details the complete process of sensor data acquisition, processing, and MQTT publishing.

```mermaid
flowchart TD
    LoopStart([Main Loop Iteration]) --> CheckInterval{Sync<br/>Interval<br/>Reached?}
    
    CheckInterval -->|No| CheckSensorReadTime{Individual<br/>Sensor<br/>Read Time?}
    CheckInterval -->|Yes| StartDataCollection[Start Data Collection Cycle]
    
    CheckSensorReadTime -->|DHT Interval| ReadDHT
    CheckSensorReadTime -->|MQ Interval| ReadMQ
    CheckSensorReadTime -->|Power Interval| ReadPower
    CheckSensorReadTime -->|Light Interval| ReadLight
    CheckSensorReadTime -->|PIR Check| ReadPIR
    CheckSensorReadTime -->|No| WaitLoop[Continue Loop]
    WaitLoop --> LoopStart
    
    StartDataCollection --> ReadDHT[Read DHT Sensor]
    ReadDHT --> DHTSuccess{Read<br/>Success?}
    DHTSuccess -->|No| LogDHTError[Log DHT Error<br/>Send Error MQTT]
    LogDHTError --> SetDHTDefault[Use Last Valid Value<br/>or Default]
    SetDHTDefault --> ReadMQ
    
    DHTSuccess -->|Yes| ParseDHT[Parse Temperature<br/>& Humidity]
    ParseDHT --> ValidateDHT{Within<br/>Range?}
    ValidateDHT -->|No| LogDHTError
    ValidateDHT -->|Yes| StoreDHT[Store in<br/>Global Variables]
    StoreDHT --> CheckDHTThresholds{Temperature<br/>Threshold?}
    CheckDHTThresholds -->|High Temp| TriggerTempAlert[Trigger High Temp Alert<br/>Activate Buzzer]
    CheckDHTThresholds -->|OK| ReadMQ
    TriggerTempAlert --> SendAlertMQTT1[Send Alert MQTT<br/>Type: _alert<br/>Immediate Publish]
    SendAlertMQTT1 --> ReadMQ
    
    ReadMQ[Read MQ Gas Sensor]
    ReadMQ --> SampleMQ[Read Analog Pin<br/>Multiple Samples]
    SampleMQ --> AverageMQ[Calculate Average<br/>Reduce Noise]
    AverageMQ --> ConvertMQ[Convert to PPM<br/>Using Calibration]
    ConvertMQ --> StoreMQ[Store in<br/>Global Variable]
    StoreMQ --> CheckMQThreshold{Gas Level<br/>> Threshold?}
    CheckMQThreshold -->|Yes| TriggerGasAlert[Trigger Gas Alert<br/>Activate Buzzer<br/>LED Indicator ON]
    TriggerGasAlert --> SendAlertMQTT2[Send Alert MQTT<br/>Type: _alert<br/>alert_type: gas_detected]
    SendAlertMQTT2 --> ReadPIR
    CheckMQThreshold -->|No| LEDOff[Turn Off MQ<br/>Indicator LED]
    LEDOff --> ReadPIR
    
    ReadPIR[Read PIR Motion Sensor]
    ReadPIR --> PIRState{Motion<br/>Detected?}
    PIRState -->|Yes| SetMotionFlag[Set Motion Flag<br/>Update Timestamp]
    PIRState -->|No| ClearMotionFlag[Clear Motion Flag]
    SetMotionFlag --> CheckLightLogic[Check Auto Light Logic]
    ClearMotionFlag --> CheckLightLogic
    CheckLightLogic --> ReadLight
    
    ReadLight[Read Light Sensor LDR]
    ReadLight --> SampleLight[Read Analog Pin<br/>Multiple Samples]
    SampleLight --> AverageLight[Calculate Average]
    AverageLight --> ConvertLux[Convert to Lux<br/>Using Calibration]
    ConvertLux --> StoreLight[Store in<br/>Global Variable]
    StoreLight --> EvalAutoLight{Auto Mode<br/>Enabled?}
    EvalAutoLight -->|No| ManualControl[Check Manual<br/>Button State]
    ManualControl --> ReadPower
    
    EvalAutoLight -->|Yes| CheckConditions{Light < Threshold<br/>AND<br/>Motion Detected?}
    CheckConditions -->|Yes| TurnOnRelay[Turn ON Relay<br/>GPIO HIGH]
    CheckConditions -->|No| CheckTimeout{Relay ON<br/>AND<br/>Timeout Reached?}
    CheckTimeout -->|Yes| TurnOffRelay[Turn OFF Relay<br/>GPIO LOW]
    CheckTimeout -->|No| ReadPower
    TurnOnRelay --> ReadPower
    TurnOffRelay --> ReadPower
    
    ReadPower[Read Power Sensors]
    ReadPower --> SampleVoltage[Sample ZMPT101B<br/>Voltage Sensor<br/>100+ Samples]
    SampleVoltage --> CalculateRMSV[Calculate RMS Voltage<br/>AC Waveform Analysis]
    CalculateRMSV --> SampleCurrent[Sample ACS712<br/>Current Sensor<br/>100+ Samples]
    SampleCurrent --> CalculateRMSI[Calculate RMS Current<br/>AC Waveform Analysis]
    CalculateRMSI --> CalculatePower[Calculate Power<br/>P = V × I]
    CalculatePower --> UpdateEnergy[Update Energy Counter<br/>kWh = ∫P dt]
    UpdateEnergy --> StorePower[Store V, I, P, kWh<br/>in Global Variables]
    StorePower --> CheckPowerThreshold{Power<br/>> Threshold?}
    CheckPowerThreshold -->|Yes| TriggerPowerAlert[Trigger Power Alert<br/>Overload Detection]
    TriggerPowerAlert --> SendAlertMQTT3[Send Alert MQTT<br/>Type: _alert<br/>alert_type: power_overload]
    SendAlertMQTT3 --> PreparePayload
    CheckPowerThreshold -->|No| PreparePayload
    
    PreparePayload[Prepare JSON Payload]
    PreparePayload --> CreateJSON[Create JSON Object<br/>StaticJsonDocument]
    CreateJSON --> AddType[Add type: '_sensor_data']
    AddType --> AddPayload[Add payload object]
    AddPayload --> AddNodeInfo[Add node_name, timestamp]
    AddNodeInfo --> AddDHTData[Add temperature, humidity]
    AddDHTData --> AddMQData[Add mq_value, mq_ppm]
    AddMQData --> AddLightData[Add light_level, light_lux]
    AddLightData --> AddMotionData[Add motion_detected]
    AddMotionData --> AddPowerData[Add acs_voltage, acs_current<br/>acs_power, acs_energy]
    AddPowerData --> AddRelayStates[Add relay_1_state, relay_2_state]
    AddRelayStates --> SerializeJSON[Serialize to String<br/>serializeJson]
    
    SerializeJSON --> CheckMQTT{MQTT<br/>Connected?}
    CheckMQTT -->|No| AttemptReconnect[Attempt MQTT Reconnect]
    AttemptReconnect --> ReconnectSuccess{Success?}
    ReconnectSuccess -->|No| LogMQTTError[Log MQTT Error<br/>Store Data Locally]
    LogMQTTError --> UpdateLCD
    ReconnectSuccess -->|Yes| PublishData
    
    CheckMQTT -->|Yes| PublishData[Publish to MQTT<br/>Topic: node/send<br/>QoS: 1]
    PublishData --> PublishSuccess{Published?}
    PublishSuccess -->|No| LogPublishError[Log Publish Error<br/>Retry Queue]
    LogPublishError --> UpdateLCD
    
    PublishSuccess -->|Yes| IncrementCounter[Increment Publish Counter<br/>Update Stats]
    IncrementCounter --> WaitAck[Wait for PUBACK<br/>from Broker]
    WaitAck --> UpdateLCD[Update LCD Display<br/>Show Latest Values<br/>Connection Status]
    
    UpdateLCD --> CycleLCDPages{Multiple<br/>LCD Pages?}
    CycleLCDPages -->|Yes| RotatePages[Rotate Display Pages<br/>Every 3 seconds]
    CycleLCDPages -->|No| DisplayMain[Display Main Page]
    RotatePages --> ListenCommands
    DisplayMain --> ListenCommands
    
    ListenCommands[Check for MQTT Commands<br/>Topic: node/cmd]
    ListenCommands --> CommandReceived{Command<br/>Received?}
    CommandReceived -->|No| CheckButtons
    
    CommandReceived -->|Yes| ParseCommand[Parse Command JSON]
    ParseCommand --> CommandType{Command<br/>Type?}
    
    CommandType -->|_command| ExtractCmd[Extract cmd field]
    ExtractCmd --> ExecCommand{Execute<br/>Command}
    ExecCommand -->|toggle_light| ToggleRelay[Toggle Relay State]
    ExecCommand -->|toggle_light_off| ForceOffRelay[Force Relay OFF]
    ExecCommand -->|restart| SystemRestart[System Restart<br/>ESP.restart]
    ExecCommand -->|reset_config| ResetConfig[Reset Config<br/>to Factory Defaults]
    
    ToggleRelay --> SendCmdAck
    ForceOffRelay --> SendCmdAck
    SystemRestart --> SendCmdAck
    ResetConfig --> ClearEEPROM[Clear EEPROM/SPIFFS]
    ClearEEPROM --> SendCmdAck
    
    CommandType -->|_config_update| ExtractConfig[Extract config object]
    ExtractConfig --> ValidateConfig{Valid<br/>Config?}
    ValidateConfig -->|No| SendErrorAck[Send Error ACK<br/>Invalid Config]
    SendErrorAck --> CheckButtons
    
    ValidateConfig -->|Yes| UpdateVariables[Update Runtime Variables<br/>Thresholds, Intervals]
    UpdateVariables --> SaveToEEPROM[Save Config to<br/>EEPROM/SPIFFS]
    SaveToEEPROM --> SendCmdAck[Send ACK MQTT<br/>Type: _ack<br/>status: success]
    SendCmdAck --> CheckButtons
    
    CheckButtons[Check Physical Buttons]
    CheckButtons --> WiFiButtonPressed{WiFi Reset<br/>Button Held<br/>5 seconds?}
    WiFiButtonPressed -->|Yes| ClearWiFiConfig[Clear WiFi Credentials<br/>Restart to AP Mode]
    ClearWiFiConfig --> SystemRestart
    
    WiFiButtonPressed -->|No| ManualButtonPressed{Manual Light<br/>Button<br/>Pressed?}
    ManualButtonPressed -->|Yes| ManualToggle[Toggle Relay Manually<br/>Override Auto Mode]
    ManualToggle --> Debounce[Debounce Delay]
    Debounce --> LoopStart
    
    ManualButtonPressed -->|No| CheckWatchdog[Feed Watchdog Timer]
    CheckWatchdog --> LoopStart
    
    style ReadDHT fill:#e3f2fd
    style ReadMQ fill:#fff3e0
    style ReadPIR fill:#e8f5e9
    style ReadLight fill:#f3e5f5
    style ReadPower fill:#ffe0b2
    style PublishData fill:#c8e6c9
    style TriggerGasAlert fill:#ffcdd2
    style TriggerTempAlert fill:#ffcdd2
    style TriggerPowerAlert fill:#ffcdd2
```

### Data Publishing Characteristics

**Sensor Polling Intervals**
- **DHT11/22**: 2000ms (2 seconds) - Limited by sensor response time
- **MQ Gas Sensor**: 1000ms (1 second) - Continuous monitoring for safety
- **PIR Motion**: 500ms (0.5 seconds) - Fast response for automation
- **Light Sensor**: 1000ms (1 second) - Ambient light monitoring
- **Power Sensors**: 100ms (0.1 seconds) - High-frequency sampling for AC waveform accuracy

**MQTT Publishing Strategy**
- **Periodic Sync**: Every 60 seconds (configurable via `sync_interval`)
- **Immediate Alerts**: Threshold breaches published instantly, bypassing sync interval
- **QoS Level 1**: At least once delivery guarantee with PUBACK acknowledgment
- **Retry Logic**: Failed publishes queued for retry with exponential backoff

**Data Format & Structure**
```json
{
  "type": "_sensor_data",
  "payload": {
    "node_name": "Living Room Node",
    "timestamp": 1705315200000,
    "temperature": 28.5,
    "humidity": 65.2,
    "mq_value": 250,
    "mq_ppm": 45,
    "light_level": 512,
    "light_lux": 150,
    "motion_detected": true,
    "acs_voltage": 230.5,
    "acs_current": 2.5,
    "acs_power": 576.25,
    "acs_energy": 12.45,
    "relay_1_state": true,
    "relay_2_state": false
  }
}
```

**Alert Payload Example**
```json
{
  "type": "_alert",
  "payload": {
    "alert_type": "gas_detected",
    "message": "High gas levels detected! MQ Value: 850 PPM",
    "severity": "critical",
    "timestamp": 1705315260000,
    "sensor_value": 850,
    "threshold": 400
  }
}
```

**Error Reporting**
```json
{
  "type": "_error",
  "payload": {
    "error_type": "dht_read_failure",
    "message": "Failed to read from DHT sensor after 3 retries",
    "timestamp": 1705315280000,
    "component": "DHT11",
    "pin": 4
  }
}
```

---

### Operational Logic
The system operates on a non-blocking loop structure:

1.  **Initialization**:
    *   Loads settings from EEPROM/SPIFFS.
    *   Attempts to connect to the last known Wi-Fi. If it fails or is unconfigured, it launches a generic "Captive Portal" allowing the user to configure Network and MQTT credentials via a phone or PC.

2.  **Sensor Handling**:
    *   **Polling**: Sensors are polled at defined intervals (e.g., Temperature every 2 seconds, Power every 100ms) to ensure responsiveness without flooding the processor.
    *   **Smoothing**: Analog sensors (ACS712, ZMPT101B) use sampling algorithms to calculate RMS (Root Mean Square) values for accurate AC readings.

3.  **Automation Rules**:
    *   **Light Control**: If `Ambient Light < Threshold` AND `Motion Detected`, the Relay is triggered ON. It turns OFF after a timeout.
    *   **Safety**: If `Gas > Threshold` or `Temp > Threshold`, the **Buzzer** sounds and a specific Alert MQTT message is sent immediately, bypassing the normal sync interval.

## Software Features

### 1. Modular Architecture
The code is split into independent modules for each component. This makes code maintenance and feature addition easier.
- `init[Component]()`: Initialization routines.
- `maintain[Component]()` or Loop logic: Handled in the main loop or timer-based checks.

### 2. Connectivity & Communication
- **WiFi Manager**: Onboard access point generation for easy detailed Wi-Fi credential configuration without hardcoding.
- **MQTT Protocol**:
    - **Publish Topic**: `node/send` - Sends JSON payloads containing sensor readings.
    - **Subscribe Topic**: `node/cmd` - Listens for remote commands (configuration updates, actuator control).

### 3. Dynamic Configuration
Key parameters are configurable (likely stored in persistent memory):
- **Network**: MQTT Broker IP, Port, Credentials.
- **Sensor Thresholds**: Trigger values for Light, Temperature, and Gas.
- **Intervals**: Read and Sync frequency timers.

## Installation & Setup

### Prerequisites
- **Arduino IDE**: Download and install the latest version.
- **Board Drivers**: Ensure drivers for your specific ESP board (CH340, CP210x) are installed.

### Steps
1.  **Library Configuration**:
    The generic `libraries/` folder is included. You can either copy these to your Arduino `libraries` folder or ensure the IDE points to this location.
2.  **Open Project**:
    Navigate to `main/` and open `main.ino`. The Arduino IDE should automatically load all associated `.h` and `.ino` tabs.
3.  **Port Selection**:
    Select your board type (e.g., `NodeMCU 1.0 (ESP-12E Module)`) and the correct COM port.
4.  **Upload**:
    Compile and upload the firmware.

## Usage
1.  **Initial Boot**: The system will initialize components and display a progress bar on the LCD.
2.  **Configuration Mode**: If Wi-Fi is not configured, the device may broadcast a hotspot. Connect to it to set up local Wi-Fi credentials.
3.  **Operation**: Once connected, the device will periodically read sensors and publish data to the configured MQTT broker. "Long Beep" indicates the system is ready and running.

## Visuals

### Assembled Device
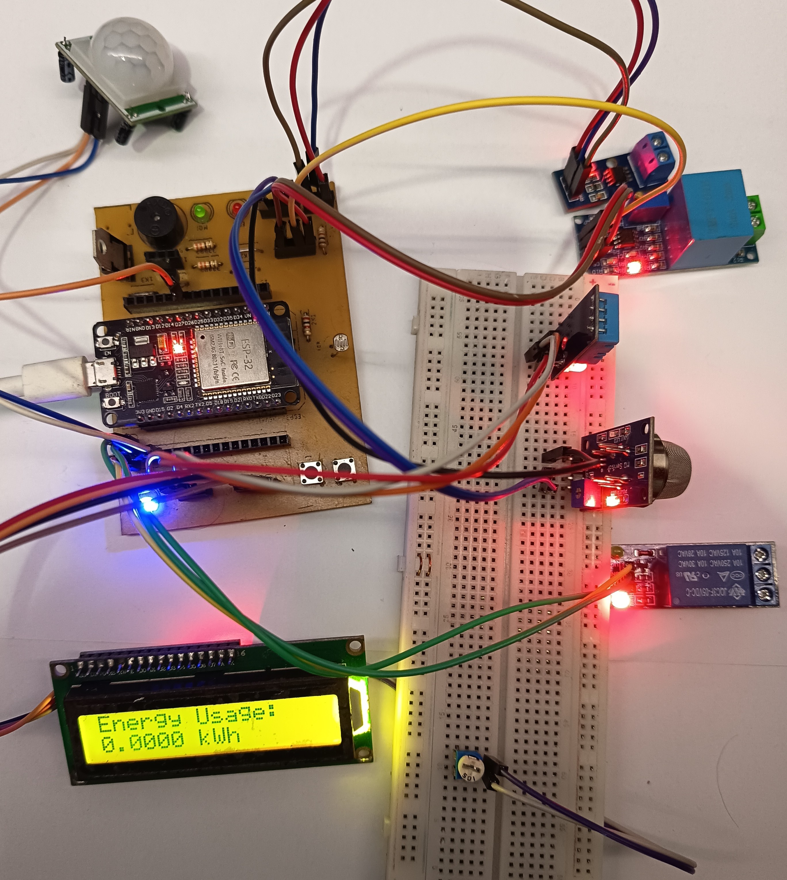
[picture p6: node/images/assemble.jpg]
Assembled Device


---

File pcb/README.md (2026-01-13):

# PCB Design - QHome Automation System

## Overview
This directory contains the Eagle CAD design files for the **QHome** main controller board. This PCB is the hardware backbone of the Home Automation System, designed to integrate the microcontroller with various environmental sensors, power monitoring modules, and communication interfaces.

## Project Structure
- **[QHome.sch](QHome.sch)**: The schematic design file detailing the circuit logic and connections.
- **[QHome.brd](QHome.brd)**: The printed circuit board layout file used for fabrication.
- **[QHome.dru](QHome.dru)**: The Design Rule Check (DRC) file defining manufacturing constraints.

## Visuals

### Schematic Diagram
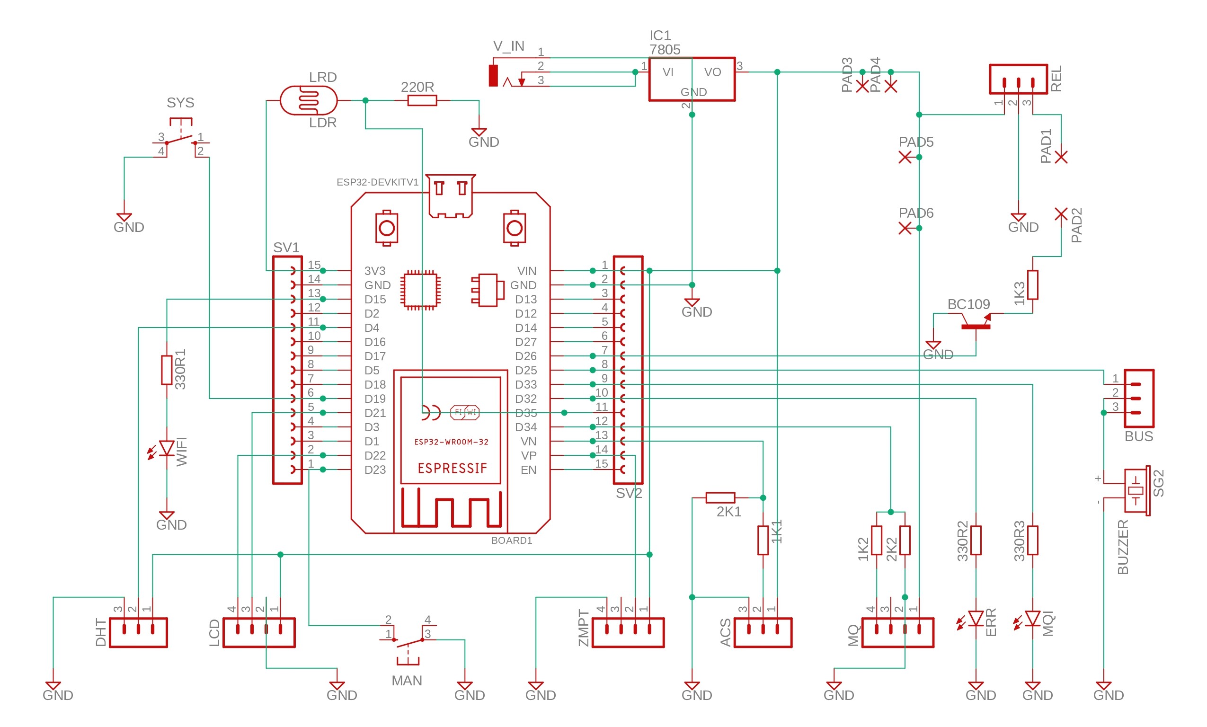
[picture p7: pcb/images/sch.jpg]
Schematic Design


### PCB Layout (Trace View)
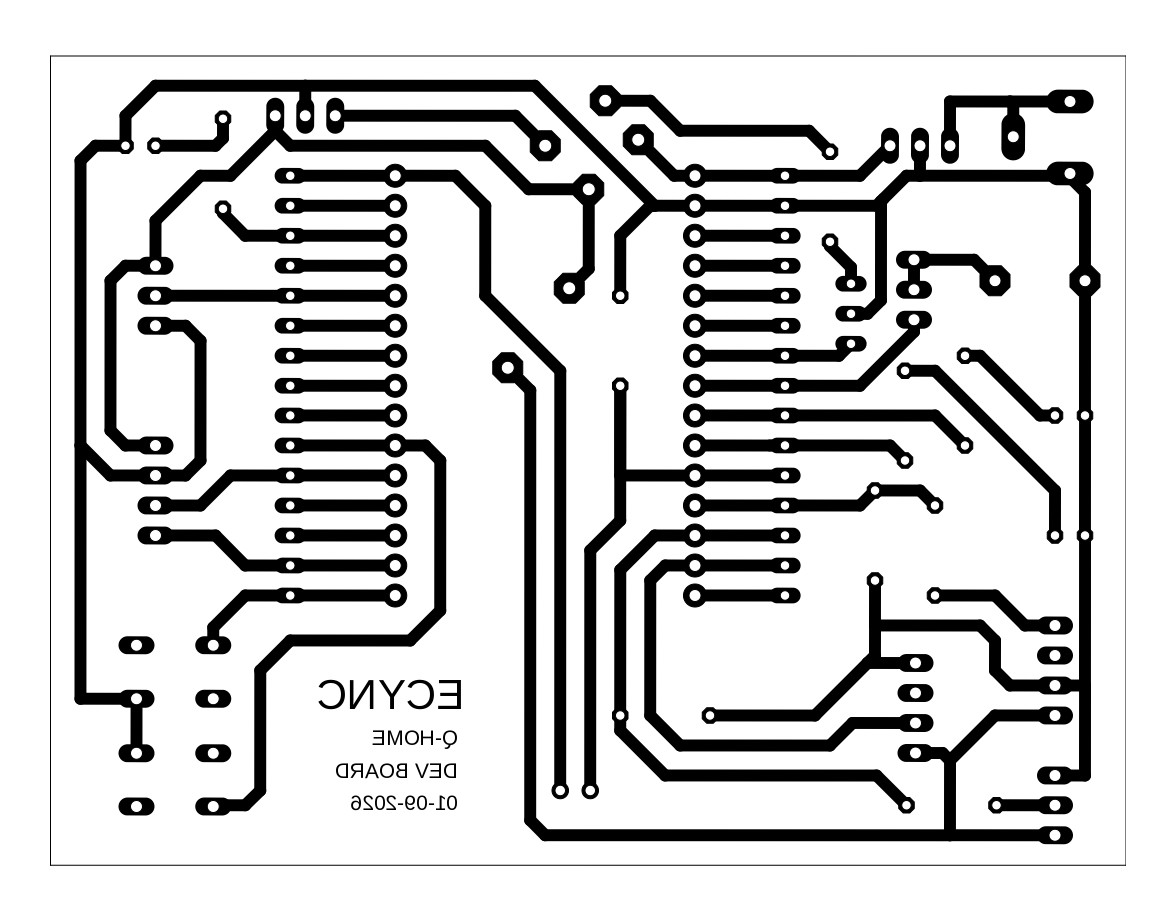
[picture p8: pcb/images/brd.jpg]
PCB Layout


### Component View (3D/Assembly)
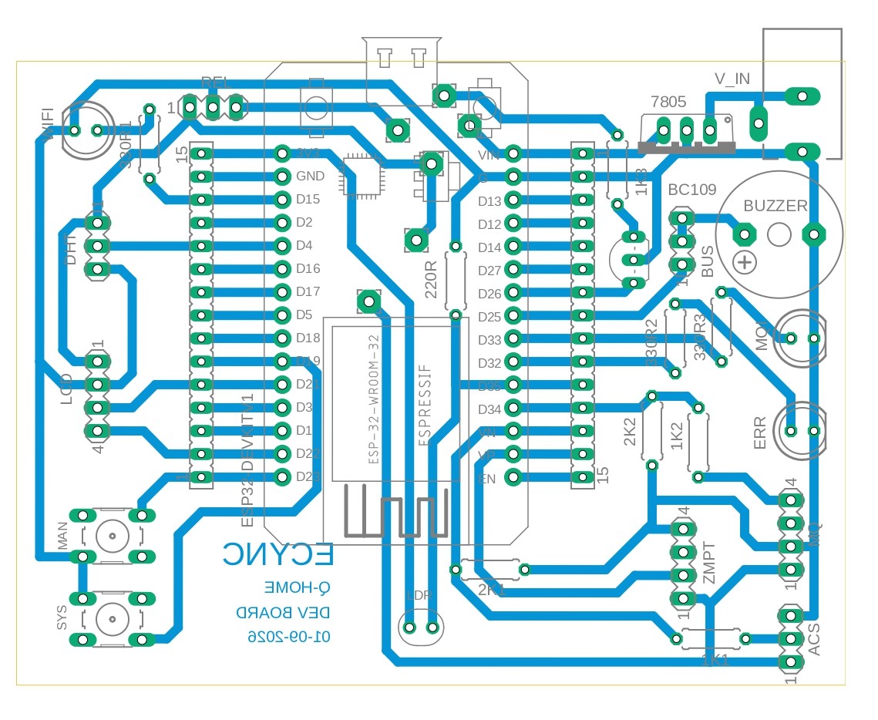
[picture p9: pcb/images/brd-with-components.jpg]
PCB Assembly


## Hardware Specifications

### Supported Microcontroller
The board is designed to host an ESP-based microcontroller (e.g., ESP8266 NodeMCU or ESP32), handling Wi-Fi connectivity and MQTT communication.

### Sensor & Peripheral Interfaces
Based on the firmware modules, this PCB includes interfaces for:

1.  **Power Monitoring**:
    *   **Voltage**: Interface for ZMPT101B AC voltage sensor.
    *   **Current**: Interface for ACS712 current sensor.
2.  **Environmental Monitoring**:
    *   **Climate**: Header for DHT11/DHT22 (Temperature & Humidity).
    *   **Air Quality**: Heading for MQ-series gas sensors (e.g., MQ-2, MQ-135).
    *   **Light**: Analog input for Light Dependent Resistor (LDR).
    *   **Presence**: Input for PIR Motion Sensor.
3.  **User Interface**:
    *   **Display**: I2C header for 16x2 or 20x4 Liquid Crystal Display (LCD).

## Fabrication Details
*   **Layers**: 2-Layer (Top & Bottom Signal/Polygon pours).
*   **Material**: Standard FR-4.
*   **Mask**: Green (or preferred color).
*   **Silkscreen**: Top side for component placement guides.

## Assembly Instructions
1.  **PCB Manufacturing**: Export Gerber files from `QHome.brd` or send the `.brd` file directly to a supported PCB fabrication house (e.g., OSH Park, PCBWay, JLCPCB).
2.  **Sourcing Components**: Generate a Bill of Materials (BOM) from `QHome.sch` inside Eagle CAD.
3.  **Soldering**:
    *   Start with low-profile components (resistors, diodes).
    *   Install headers and connectors (JST, Dupont, or screw terminals).
    *   Solder larger modules or sockets for the microcontroller and sensors.
4.  **Testing**: Before inserting the MCU, power the board and check voltage rails (5V, 3.3V) with a multimeter to facilitate safe operation.

## Design Tools
*   **Software**: Autodesk EAGLE (or compatible EDA software like Fusion 360 Electronics).

---

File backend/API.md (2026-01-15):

# Backend API Reference

Base URL: `http://localhost:3000/api`

## Authentication
All HTTP endpoints require the following headers:
- `X-USERNAME`: The username configured in environment variables.
- `X-PASSWORD`: The password configured in environment variables.

---

## 📡 MQTT Message Flow Diagram

This diagram illustrates the complete message flow between IoT nodes, MQTT broker, and the backend service.

```mermaid
sequenceDiagram
    participant Node as IoT Node<br/>(ESP32)
    participant Broker as MQTT Broker<br/>(WebSocket)
    participant Backend as NestJS Backend<br/>(Gateway)
    participant DB as MongoDB
    participant Socket as Socket.IO<br/>(Clients)
    participant API as REST API<br/>(Controllers)
    
    Note over Node,Socket: System Initialization
    Node->>Broker: CONNECT (Client ID: node_001)
    Broker-->>Node: CONNACK
    Node->>Broker: SUBSCRIBE (node/cmd)
    Backend->>Broker: CONNECT (Client ID: backend_service)
    Broker-->>Backend: CONNACK
    Backend->>Broker: SUBSCRIBE (node/send)
    
    Note over Node,Socket: Sensor Data Publishing
    loop Every Sync Interval (e.g., 60s)
        Node->>Node: Read all sensors<br/>(DHT, MQ, ACS, ZMPT, PIR, LDR)
        Node->>Node: Create JSON payload<br/>{type: "_sensor_data", payload: {...}}
        Node->>Broker: PUBLISH (node/send)<br/>Topic: node/send<br/>Payload: Sensor Data JSON
        Broker->>Backend: FORWARD (node/send message)
        Backend->>Backend: Validate & Parse JSON
        Backend->>Backend: Extract data fields<br/>(temp, humidity, power, etc.)
        
        par Parallel Processing
            Backend->>DB: INSERT (NodeSensorData collection)<br/>Save sensor readings
            DB-->>Backend: Acknowledgment
        and
            Backend->>Socket: EMIT (sensorUpdate)<br/>Broadcast to all clients
            Socket-->>Frontend: Real-time update
        end
    end
    
    Note over Node,Socket: Alert & Error Handling
    Node->>Node: Detect threshold breach<br/>(e.g., Gas > 400 PPM)
    Node->>Broker: PUBLISH (node/send)<br/>{type: '_alert', payload: {alert_type: 'gas_detected'}}
    Broker->>Backend: FORWARD (alert message)
    Backend->>Backend: Parse alert type
    Backend->>DB: INSERT (NodeAlert collection)
    Backend->>Socket: EMIT (criticalAlert)<br/>Immediate notification
    Socket-->>Frontend: Show alert popup
    
    Node->>Node: Sensor read failure<br/>(e.g., DHT timeout)
    Node->>Broker: PUBLISH (node/send)<br/>{type: '_error', payload: {error_type: 'dht_failure'}}
    Broker->>Backend: FORWARD (error message)
    Backend->>DB: INSERT (NodeError collection)
    Backend->>Socket: EMIT (systemError)
    
    Note over Node,Socket: Command & Control Flow
    Frontend->>API: HTTP POST /mqtt/command/toggle_light<br/>Headers: X-USERNAME, X-PASSWORD
    API->>API: Authenticate request
    API->>API: Create command payload<br/>{type: '_command', payload: {cmd: 'toggle_light'}}
    API->>Broker: PUBLISH (node/cmd)<br/>Topic: node/cmd<br/>Payload: Command JSON
    API-->>Frontend: 202 Accepted
    Broker->>Node: FORWARD (node/cmd message)
    Node->>Node: Parse command type
    Node->>Node: Execute action<br/>(Toggle relay GPIO)
    Node->>Broker: PUBLISH (node/send)<br/>{type: '_ack', payload: {status: 'success'}}
    Broker->>Backend: FORWARD (acknowledgment)
    Backend->>Socket: EMIT (commandAck)
    Socket-->>Frontend: Update UI state
    
    Note over Node,Socket: Configuration Update Flow
    Frontend->>API: HTTP POST /mqtt/config<br/>Body: {config: {sensors: {...}, system: {...}}}
    API->>API: Validate config schema
    API->>DB: UPDATE (NodeConfig collection)<br/>Save new configuration
    DB-->>API: Update confirmed
    API->>API: Create config payload<br/>{type: '_config_update', payload: {config: {...}}}
    API->>Broker: PUBLISH (node/cmd)<br/>Topic: node/cmd
    API-->>Frontend: 202 Accepted
    Broker->>Node: FORWARD (config message)
    Node->>Node: Parse config fields
    Node->>Node: Update runtime variables<br/>(thresholds, intervals)
    Node->>Node: Save to EEPROM/SPIFFS
    Node->>Broker: PUBLISH (node/send)<br/>{type: '_ack', payload: {config_applied: true}}
    Broker->>Backend: FORWARD (ack)
    Backend->>Socket: EMIT (configUpdated)
    
    Note over Node,Socket: Heartbeat & Keepalive
    loop Every 120s
        Node->>Broker: PINGREQ
        Broker-->>Node: PINGRESP
    end
    
    loop Every 60s
        Backend->>Broker: PINGREQ
        Broker-->>Backend: PINGRESP
    end
```

### Message Type Reference

| Message Type | Direction | Topic | Purpose |
|---|---|---|---|
| `_sensor_data` | Node → Backend | `node/send` | Regular telemetry data transmission |
| `_alert` | Node → Backend | `node/send` | Critical safety events (gas, fire, motion) |
| `_error` | Node → Backend | `node/send` | System faults and sensor failures |
| `_ack` | Node → Backend | `node/send` | Command acknowledgment responses |
| `_command` | Backend → Node | `node/cmd` | Immediate control actions (toggle, restart) |
| `_config_update` | Backend → Node | `node/cmd` | Configuration parameter updates |

---

## HTTP Endpoints

### 1. System Status
Get the current configuration from the database (mirrors the node's config).

- **URL**: `/mqtt/status`
- **Method**: `GET`
- **Response**: `200 OK`
```json
// Returns NodeConfig object
{
    "_id": "...",
    "node_name": "Living Room",
    "wifi_password": "...",
    "sync_interval": 60000,
    "sensors": { ... }
}
```

### 2. Error Logs
Get a list of recent error reports from the node.

- **URL**: `/mqtt/errors`
- **Method**: `GET`
- **Query Params**:
    - `limit`: (Optional) Number of records to return. Default: 10.
- **Response**: `200 OK`
```json
[
    {
        "error_type": "dht_read_failure",
        "message": "Failed to read from DHT sensor",
        "createdAt": "2026-01-13T10:00:00.000Z"
    }
]
```

### 3. Alert Logs
Get a list of critical alerts (Gas, Fire, Motion).

- **URL**: `/mqtt/alerts`
- **Method**: `GET`
- **Query Params**:
    - `limit`: (Optional) Number of records to return. Default: 10.
- **Response**: `200 OK`
```json
[
    {
        "alert_type": "gas_detected",
        "message": "High gas levels detected!",
        "createdAt": "2026-01-13T10:05:00.000Z"
    }
]
```

### 4. Historical Sensor Data
Get aggregated sensor readings for a specific date.

- **URL**: `/mqtt/sensor-data/:date`
- **Method**: `GET`
- **URL Params**:
    - `date`: Valid Javascript Timestamp (ms).
- **Response**: `200 OK`
```json
[
    {
        "tempeture": 28.5,
        "humidity": 60,
        "mq_value": 150,
        "acs_power": 120.5,
        "createdAt": "..."
    }
]
```

### 5. Send Command
Send an immediate control command to the node.

- **URL**: `/mqtt/command/:cmd`
- **Method**: `POST`
- **URL Params**:
    - `cmd`: Valid command type. 
      - `restart`
      - `reset_config`
      - `toggle_light`
      - `toggle_light_off`
- **Response**: `202 Accepted`

### 6. Update Configuration
Update the system configuration and push changes to the node via MQTT.

- **URL**: `/mqtt/config`
- **Method**: `POST`
- **Body**:
```json
{
  "config": {
    "system": {
      "wifi_password": "newpass",
      "sync_interval": 30000
    },
    "sensors": {
      "dht_sensor": {
        "enabled": true,
        "high_temp_value": 40,
        "low_temp_value": 0,
        "read_interval": 2000
      },
      // ... other sensors
    }
  }
}
```
- **Response**: `202 Accepted`

---

## MQTT Interface

The backend acts as an MQTT Client wrapper.

### Subscribed Topics
- **`node/send`**: Listens for payloads from the node.
    - **Wrappers**:
        - `_ack`: Handshake payload.
        - `_sensor_data`: Telemetry.
        - `_alert`: Critical events.
        - `_error`: System faults.

### Published Topics
- **`node/cmd`**: Used to send commands to the node.
    - Payload Structure:
    ```json
    {
        "type": "_config_update" | "_command",
        "payload": { ... }
    }
    ```

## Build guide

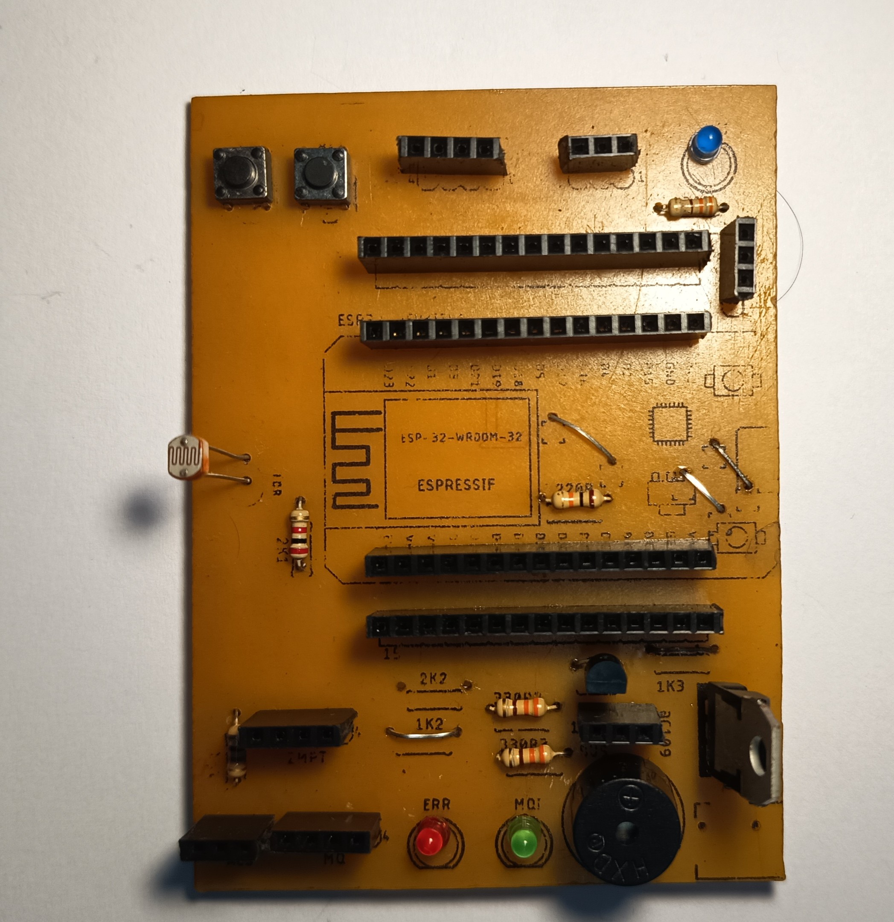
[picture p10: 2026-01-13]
pcb/images/pcb-solder.jpg

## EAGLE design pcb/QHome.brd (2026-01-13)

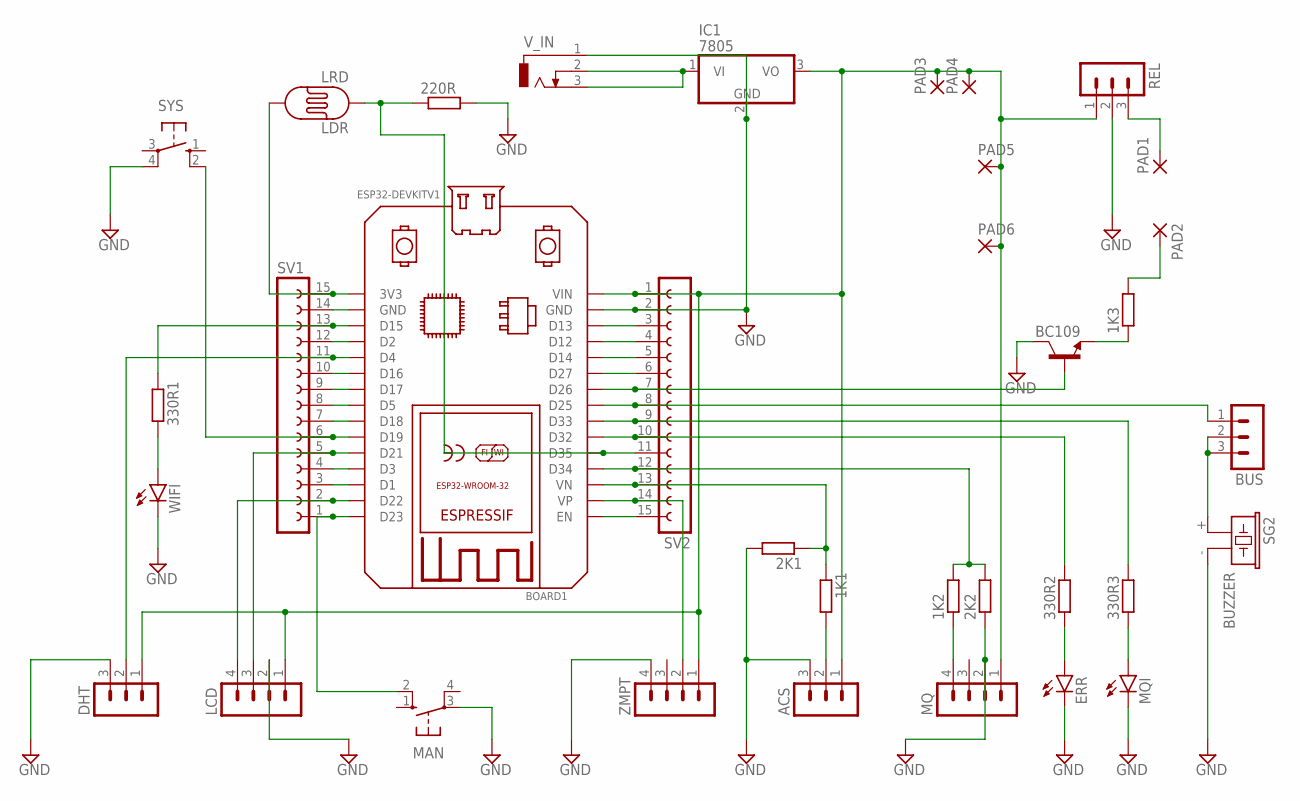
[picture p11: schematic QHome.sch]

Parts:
1K1, 1K2, 1K3, 2K1, 2K2, 220R, 330R1, 330R2, 330R3: R-EU_0207/7; 0207/7
ACS: MA03-1
BC109: BF422-NPN-TO92-BCE; TO92-BCE
BOARD1: ESP32DEVKITV1; ESP32-DEVKITV1
BUS: MA03-1
DHT: MA03-1
ERR: LED5MM
IC1: 7805; TO220V
LCD: MA04-1
LDR: LRD; ON_BOARD
MAN: 10-XX; B3F-10XX
MQ: MA04-1
MQI: LED5MM
PAD1, PAD2, PAD3, PAD4, PAD5, PAD6: 2,54/1,1
REL: MA03-1
SG2: BUZZER; F/CM12P
SV1, SV2: FE15-1; FE15
SYS: 10-XX; B3F-10XX
V_IN: DCJ0303
WIFI: LED5MM
ZMPT: MA04-1

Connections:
GND: 2K1.2, 2K2.1, 220R.2, ACS.3, BC109.C, BOARD1.GND, DHT.3, ERR.K (C), IC1.2 (GND), LCD.2, MAN.3, MQ.2, MQI.K (C), REL.2, SG2.- (2), SV2.2, SYS.4 (P1), V_IN.1, WIFI.K (C), ZMPT.4
unnamed: IC1.1 (VI), V_IN.2, V_IN.3
unnamed: BOARD1.VP, SV2.14, ZMPT.2
unnamed: BOARD1.3V3, LDR.2, SV1.15
unnamed: 1K1.1, 2K1.1, BOARD1.VN, SV2.13
unnamed: 1K1.2, ACS.2
unnamed: 1K2.1, MQ.4
unnamed: ACS.1, BOARD1.VIN, DHT.1, IC1.3 (VO), LCD.1, MQ.1, PAD3.1, PAD4.1, PAD5.1, PAD6.1, REL.1, SV2.1, ZMPT.1
unnamed: 1K2.2, 2K2.2, BOARD1.D34, SV2.12
unnamed: 220R.1, BOARD1.D35, LDR.1, SV2.11
unnamed: BOARD1.D21, LCD.3, SV1.5
unnamed: BOARD1.D22, LCD.4, SV1.2
unnamed: 330R1.2, WIFI.A
unnamed: BOARD1.D4, DHT.2, SV1.11
unnamed: 330R2.1, ERR.A
unnamed: 330R1.1, BOARD1.D15, SV1.13
unnamed: 330R3.2, BOARD1.D33, SV2.9
unnamed: 330R3.1, MQI.A
unnamed: 330R2.2, BOARD1.D32, SV2.10
unnamed: BOARD1.D25, BUS.1, SV2.8
unnamed: BUS.2, BUS.3, SG2.+ (1)
unnamed: 1K3.2, PAD2.1
unnamed: BOARD1.D19, SV1.6, SYS.2 (S1)
unnamed: BOARD1.D23, MAN.2 (S1), SV1.1
unnamed: BOARD1.D1, SV1.3
unnamed: BOARD1.D3, SV1.4
unnamed: BOARD1.D18, SV1.7
unnamed: BOARD1.D5, SV1.8
unnamed: BOARD1.D17, SV1.9
unnamed: BOARD1.D16, SV1.10
unnamed: BOARD1.D2, SV1.12
unnamed: BOARD1.GND@1 (GND), SV1.14
unnamed: BOARD1.D13, SV2.3
unnamed: BOARD1.D12, SV2.4
unnamed: BOARD1.D14, SV2.5
unnamed: BOARD1.D27, SV2.6
unnamed: BOARD1.EN, SV2.15
unnamed: BC109.B, BOARD1.D26, SV2.7
unnamed: PAD1.1, REL.3
unnamed: 1K3.1, BC109.E

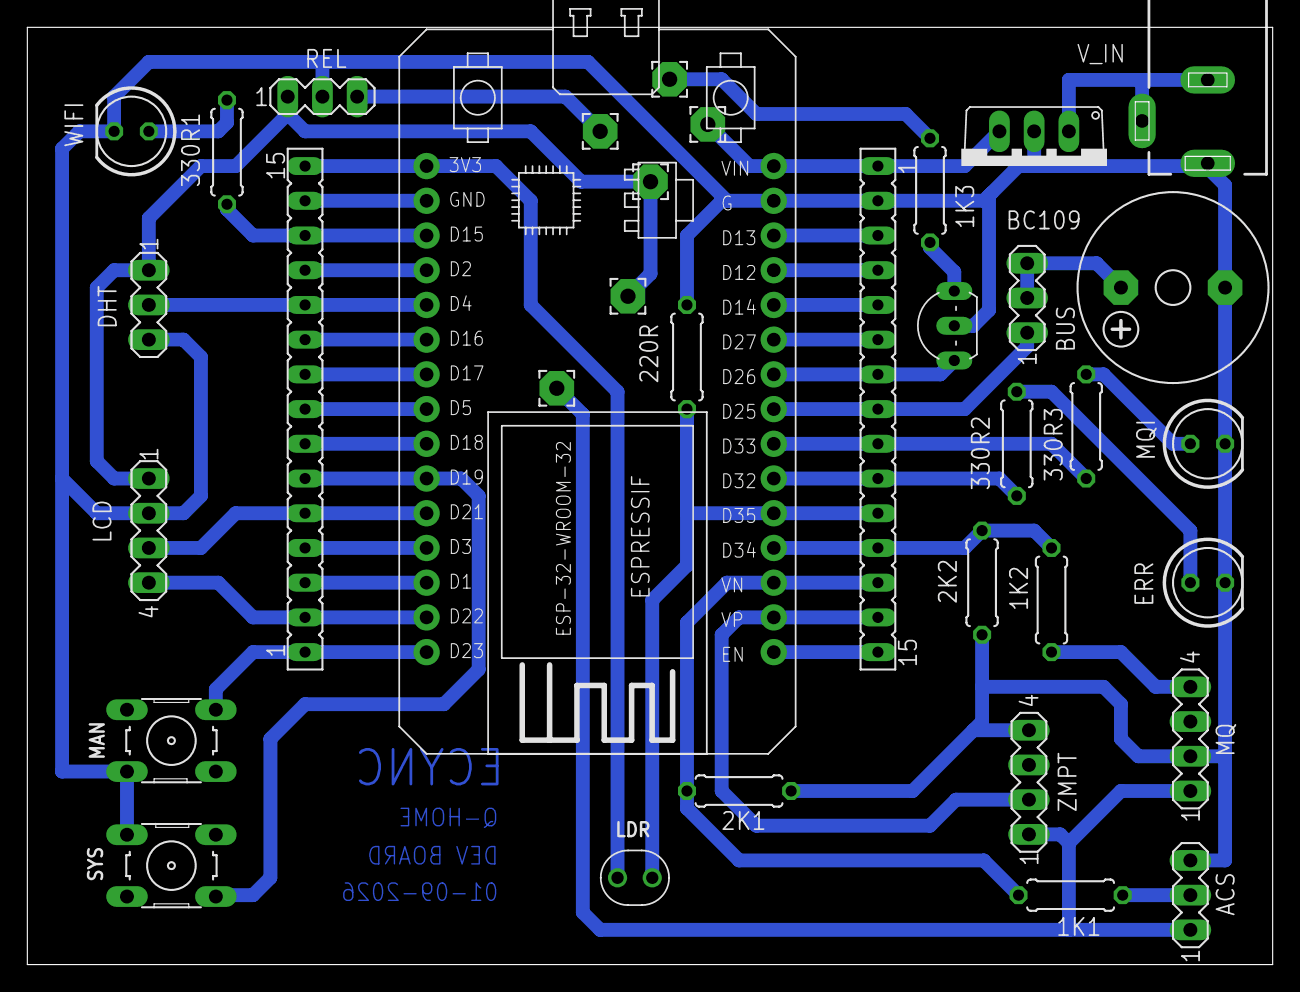
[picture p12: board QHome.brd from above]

Board: 2 copper layers, 91.1 x 68.6 mm, 35 parts (0 on the bottom side), 40 nets.

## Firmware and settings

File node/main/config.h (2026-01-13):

// config.h
#ifndef CONFIG_H
#define CONFIG_H


// Default MQTT Server
#define DEFAULT_MQTT_SERVER_IP "your-mqtt-server.com"
#define DEFAULT_MQTT_SERVER_PORT 1883
#define DEFAULT_MQTT_SERVER_USER "your_username"
#define DEFAULT_MQTT_SERVER_PASS "your_password"


/**
* EDITABLE CONFIGURATIONS
*/
String NODE_NAME;  // Device node name

String WIFI_PASSWORD;  // Config potal password

int SYNC_INTERVAL;  // Server sync interval in milliseconds

// MQTT Server
String MQTT_SERVER_IP;
int MQTT_SERVER_PORT;
String MQTT_SERVER_USER;
String MQTT_SERVER_PASS;

// DHT Sensor
bool ENABLE_DHT_SENSOR;
float HIGH_TEMP_DETECTION_VALUE;
float LOW_TEMP_DETECTION_VALUE;
int DHT_SENSOR_READ_INTERVAL;

// PIR Sensor
bool ENABLE_PIR_SENSOR;
int PIR_SENSOR_READ_INTERVAL;

// MQ Sensor
bool ENABLE_MQ_SENSOR;
int MQ_SENSOR_DITECTION_VALUE;
int MQ_SENSOR_READ_INTERVAL;

// Light Sensor
bool ENABLE_LIGHT_SENSOR;
int LIGHT_SENSOR_TRIGGER_VALUE;
int LIGHT_SENSOR_READ_INTERVAL;

// ZMPT Sensor
bool ENABLE_ZMPT_SENSOR;
float HIGH_ZMPT_DETECTION_VALUE;
float LOW_ZMPT_DETECTION_VALUE;
int ZMPT_SENSOR_READ_INTERVAL;

// ACS Sensor
bool ENABLE_ACS_SENSOR;
float HIGH_ACS_DETECTION_VALUE;
int ACS_SENSOR_READ_INTERVAL;


// Function declarations
void loadConfig();
void saveConfig();
void resetConfig();
void setMqttConfig(const char* server_ip, const char* server_port, const char* server_user, const char* server_pass);

#endif

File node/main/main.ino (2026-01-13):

#include "config.h"
#include "components.h"
#include "wifi_con.h"
#include "mqtt.h"
#include "dht_sensor.h"
#include "lcd.h"
#include "mq_sensor.h"
#include "light_sensor.h"
#include "pir_sensor.h"
#include "zmpt_sensor.h"
#include "acs_sensor.h"


void setup() {
  Serial.begin(115200);
  initComponents(); // Initialize components
  initLcd();        // Initialize LCD
  
  displayProgressBar(10, 1);
  initConfig();     // Initialize configurations
  
  displayProgressBar(30, 1);
  initWifi();       // Initialize WiFi
  
  displayProgressBar(50, 1);
  initMqtt();       // Initialize MQTT

  // Sensor initializations
  displayProgressBar(60, 1);
  initDhtSensor();  // Initialize DHT sensor
  
  displayProgressBar(70, 1);
  initMqSensor();   // Initialize MQ sensor
  
  displayProgressBar(80, 1);
  initLightSensor(); // Initialize Light sensor
  
  displayProgressBar(85, 1);
  initPirSensor();   // Initialize PIR sensor
  
  displayProgressBar(90, 1);
  initZmptSensor();  // Initialize ZMPT sensor
  
  displayProgressBar(95, 1);
  initAcsSensor();   // Initialize ACS sensor
  
  displayProgressBar(100, 1);
  delay(1000); // Show 100% for a moment
  clearLCD(); // Clear LCD
  longBeep(); // Indicate system ready
}

void loop() {
  handleSystemButton(); // Handle system button presses
  handleErrorIndication(); // Handle error indication
  handleWifiLed(); // Handle WiFi LED indication
  maintainWifi(); // Maintain WiFi connection
  maintainMqtt(); // Maintain MQTT connection

  // Handle manual button for light sensor
  handleManualButton();
  
  // Sensor handling
  handleDhtSensor(); // Handle DHT sensor readings
  handleMqSensor();  // Handle MQ sensor
  handleMqLed();     // Handle MQ LED
  handleLightSensor(); // Handle Light sensor
  handlePirSensor();   // Handle PIR sensor
  handleZmptSensor();  // Handle ZMPT sensor
  handleAcsSensor();   // Handle ACS sensor

  // Send sensor data
  sendSensorData();

  // Handle LCD
  handleLcd();
}

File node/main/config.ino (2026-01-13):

#include <Preferences.h>
#include "config.h"

/*
* DEFAULT CONFIGURATIONS
*/
#define DEFAULT_NODE_NAME "Q-HOME-NODE"

#define DEFAULT_WIFI_PASSWORD "changeme"

#define DEFAULT_SYNC_INTERVAL 60000 // in milliseconds

// DHT Sensor
#define DEFAULT_ENABLE_DHT_SENSOR true
#define DEFAULT_HIGH_TEMP_DETECTION_VALUE 50.0
#define DEFAULT_LOW_TEMP_DETECTION_VALUE 20.0
#define DEFAULT_DHT_SENSOR_READ_INTERVAL 5000 // 80 in milliseconds

// PIR sensor
#define DEFAULT_ENABLE_PIR_SENSOR true
#define DEFAULT_PIR_SENSOR_READ_INTERVAL 1000

// MQ Sensor
#define DEFAULT_ENABLE_MQ_SENSOR true
#define DEFAULT_MQ_SENSOR_DITECTION_VALUE 2100
#define DEFAULT_MQ_SENSOR_READ_INTERVAL 5000  // in milliseconds

// Light Sensor
#define DEFAULT_ENABLE_LIGHT_SENSOR true
#define DEFAULT_LIGHT_SENSOR_TRIGGER_VALUE 400
#define DEFAULT_LIGHT_SENSOR_READ_INTERVAL 5000  // in milliseconds

// ZMPT Sensor
#define DEFAULT_ENABLE_ZMPT_SENSOR true
#define DEFAULT_HIGH_ZMPT_DETECTION_VALUE 255.0
#define DEFAULT_LOW_ZMPT_DETECTION_VALUE 220.0
#define DEFAULT_ZMPT_SENSOR_READ_INTERVAL 5000  // in milliseconds

// ACS Sensor
#define DEFAULT_ENABLE_ACS_SENSOR true
#define DEFAULT_HIGH_ACS_DETECTION_VALUE 9.0
#define DEFAULT_ACS_SENSOR_READ_INTERVAL 5000  // in milliseconds


// Create a config object
Preferences config;
Preferences mqtt_config;

/*
* Initialize configuration by loading values from Preferences
* If no saved values exist, default values are used
*/
void initConfig() {
    Serial.print("[SYSTEM] Getting configurations...");
    config.begin("config", false); // Open Preferences with namespace "config"
    mqtt_config.begin("mqtt_config", false); // Open Preferences with namespace "mqtt_config"

    // Load configurations or use default values
    NODE_NAME = config.getString("node_name", DEFAULT_NODE_NAME);
    WIFI_PASSWORD = config.getString("wifi_password", DEFAULT_WIFI_PASSWORD);
    SYNC_INTERVAL = config.getInt("sync_interval", DEFAULT_SYNC_INTERVAL);

    MQTT_SERVER_IP = mqtt_config.getString("mqtt_server_ip", DEFAULT_MQTT_SERVER_IP);
    MQTT_SERVER_PORT = mqtt_config.getInt("mqtt_server_port", DEFAULT_MQTT_SERVER_PORT);
    MQTT_SERVER_USER = mqtt_config.getString("mqtt_server_user", DEFAULT_MQTT_SERVER_USER);
    MQTT_SERVER_PASS = mqtt_config.getString("mqtt_server_pass", DEFAULT_MQTT_SERVER_PASS);

    ENABLE_DHT_SENSOR = config.getBool("enable_dht_sensor", DEFAULT_ENABLE_DHT_SENSOR);
    HIGH_TEMP_DETECTION_VALUE = config.getFloat("high_temp_value", DEFAULT_HIGH_TEMP_DETECTION_VALUE);
    LOW_TEMP_DETECTION_VALUE = config.getFloat("low_temp_value", DEFAULT_LOW_TEMP_DETECTION_VALUE);
    DHT_SENSOR_READ_INTERVAL = config.getInt("dht_read_interval", DEFAULT_DHT_SENSOR_READ_INTERVAL);

    ENABLE_PIR_SENSOR = config.getBool("enable_pir_sensor", DEFAULT_ENABLE_PIR_SENSOR);
    PIR_SENSOR_READ_INTERVAL = config.getInt("pir_read_interval", DEFAULT_PIR_SENSOR_READ_INTERVAL);

    ENABLE_MQ_SENSOR = config.getBool("enable_mq_sensor", DEFAULT_ENABLE_MQ_SENSOR);
    MQ_SENSOR_DITECTION_VALUE = config.getInt("mq_detection_value", DEFAULT_MQ_SENSOR_DITECTION_VALUE);
    MQ_SENSOR_READ_INTERVAL = config.getInt("mq_read_interval", DEFAULT_MQ_SENSOR_READ_INTERVAL);

    ENABLE_LIGHT_SENSOR = config.getBool("enable_light_sensor", DEFAULT_ENABLE_LIGHT_SENSOR);
    LIGHT_SENSOR_TRIGGER_VALUE = config.getInt("light_trigger_value", DEFAULT_LIGHT_SENSOR_TRIGGER_VALUE);
    LIGHT_SENSOR_READ_INTERVAL = config.getInt("light_read_interval", DEFAULT_LIGHT_SENSOR_READ_INTERVAL);

    ENABLE_ZMPT_SENSOR = config.getBool("enable_zmpt_sensor", DEFAULT_ENABLE_ZMPT_SENSOR);
    HIGH_ZMPT_DETECTION_VALUE = config.getFloat("high_zmpt_value", DEFAULT_HIGH_ZMPT_DETECTION_VALUE);
    LOW_ZMPT_DETECTION_VALUE = config.getFloat("low_zmpt_value", DEFAULT_LOW_ZMPT_DETECTION_VALUE);
    ZMPT_SENSOR_READ_INTERVAL = config.getInt("zmpt_read_interval", DEFAULT_ZMPT_SENSOR_READ_INTERVAL);

    ENABLE_ACS_SENSOR = config.getBool("enable_acs_sensor", DEFAULT_ENABLE_ACS_SENSOR);
    HIGH_ACS_DETECTION_VALUE = config.getFloat("high_acs_value", DEFAULT_HIGH_ACS_DETECTION_VALUE);
    ACS_SENSOR_READ_INTERVAL = config.getInt("acs_read_interval", DEFAULT_ACS_SENSOR_READ_INTERVAL);

    config.end();
    mqtt_config.end();
    Serial.println(" DONE!");
}
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

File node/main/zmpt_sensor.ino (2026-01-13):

#include <ZMPT101B.h>
#include "config.h"
#include "payloads.h"
#include "components.h"
#include "mqtt.h"
#include "zmpt_sensor.h"

// Define AC Frequency (50Hz or 60Hz)
#define AC_FREQ 50.0
// Define Sensitivity (Calibrate this value)
#define ZMPT_SENSIVITY 500.0f 

bool zmptSensorStatus = false;
float zmptSensorValue = 0.0;

bool is_sensor_error_reported_zmpt = false;
int lastZmptAlertState = 0; // 0 = Normal, 1 = No Power, 2 = High, 3 = Low

ZMPT101B voltageSensor(ZMPT_SENSOR_PIN, AC_FREQ);

/*
* Initialize ZMPT Sensor
*/
void initZmptSensor() {
  Serial.print(F("[ZMPT] Initializing ZMPT sensor..."));
  voltageSensor.setSensitivity(ZMPT_SENSIVITY);
  
  // Test Sensor connection by reading value
  float read = voltageSensor.getRmsVoltage();
  
  if (isnan(read)) {
    Serial.println(F(" FAILED"));
    // Send error
    String payload = createErrorPayload(ErrorTypes::ZMPT_READ_FAILURE, "ZMPT sensor initialization failed");
    publishMqtt(PUB_EVENT, payload.c_str());
    zmptSensorStatus = false;
  } else {
    Serial.println(F(" OK"));
    zmptSensorStatus = true;
  }
}

/*
* Handle ZMPT Sensor (to be called in main loop)
*/
void handleZmptSensor() {
  static unsigned long lastZmptReadTime = 0;
  // Only read if sensor is enabled
  if (!ENABLE_ZMPT_SENSOR) {
    return;
  }

  // Check if it is time to read the sensor
  if (millis() - lastZmptReadTime < ZMPT_SENSOR_READ_INTERVAL) {
    return;
  }
  lastZmptReadTime = millis();

  // Read ZMPT sensor value
  zmptSensorValue = voltageSensor.getRmsVoltage();

  // Check if any reads failed
  if (isnan(zmptSensorValue)) {
    zmptSensorStatus = false;
    if (!is_sensor_error_reported_zmpt) {
      is_sensor_error_reported_zmpt = true;
      Serial.println(F("[ZMPT] Invalid ZMPT sensor reading detected!"));
      String payload = createErrorPayload(ErrorTypes::ZMPT_READ_FAILURE, "Invalid ZMPT sensor reading");
      publishMqtt(PUB_EVENT, payload.c_str());
    }
    return;
  }

  zmptSensorStatus = true;
  is_sensor_error_reported_zmpt = false;

  // Filter noise
  if (zmptSensorValue < 70.0) {
    zmptSensorValue = 0.0;
  }

  // Trigger detection
  int currentZmptState = 0;
  if (zmptSensorValue < 50.0) {
    currentZmptState = 1; // No Power
  } else if (zmptSensorValue >= HIGH_ZMPT_DETECTION_VALUE) {
    currentZmptState = 2; // High Voltage
  } else if (zmptSensorValue <= LOW_ZMPT_DETECTION_VALUE) {
    currentZmptState = 3; // Low Voltage
  } else {
    currentZmptState = 0; // Normal
  }
  
  if (currentZmptState != lastZmptAlertState) {
    if (currentZmptState == 1) { // No Power
      longBeep();
      Serial.println("[ZMPT] No power detected! Sensor Value: " + String(zmptSensorValue));
      String payload = createAlertPayload(AlertTypes::LOW_VOLTAGE, "No power detected by ZMPT sensor");
      publishMqtt(PUB_EVENT, payload.c_str());
    } else if (currentZmptState == 2) { // High Voltage
      longBeep();
      Serial.println("[ZMPT] High voltage detected! Sensor Value: " + String(zmptSensorValue));
      String payload = createAlertPayload(AlertTypes::HIGH_VOLTAGE, "High voltage detected by ZMPT sensor");
      publishMqtt(PUB_EVENT, payload.c_str());
    } else if (currentZmptState == 3) { // Low Voltage
      longBeep();
      Serial.println("[ZMPT] Low voltage detected! Sensor Value: " + String(zmptSensorValue));
      String payload = createAlertPayload(AlertTypes::LOW_VOLTAGE, "Low voltage detected by ZMPT sensor");
      publishMqtt(PUB_EVENT, payload.c_str());
    } else { // Back to normal
      shortBeep();
      Serial.println("[ZMPT] Voltage normal. Sensor Value: " + String(zmptSensorValue));
      String payload = createAlertPayload(AlertTypes::HIGH_VOLTAGE, "Voltage returned to normal"); 
      publishMqtt(PUB_EVENT, payload.c_str());
    }
    lastZmptAlertState = currentZmptState;
  }

  // Debug output
  Serial.println("[ZMPT] Sensor Value: " + String(zmptSensorValue));
}

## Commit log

2026-01-15 Add comprehensive diagrams and flow descriptions for data and software processes
    - Introduced Data Flow Diagram in README.md detailing sensor data acquisition, processing, and user interaction.
    - Added Software Flow Diagram illustrating system startup and continuous operation.
    - Included MQTT Message Flow Diagram in API.md to clarify message exchanges between components.
    - Enhanced backend processing documentation with a detailed Data Processing Flow diagram.
    - Updated frontend README.md with User Interaction Flow Diagram to depict user journeys and actions.
    - Revised node README.md to include Sensor Data Publishing Flow diagram outlining sensor data handling and MQTT publishing.
    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
2026-01-15 Fix formatting of error and success messages in flowcharts in README files
